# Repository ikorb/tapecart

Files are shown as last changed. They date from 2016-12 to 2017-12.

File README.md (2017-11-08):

# tapecart #

tapecart - a tape port storage pod for the C64

Copyright (C) 2013-2017 by Ingo Korb <ingo@akana.de>  
All rights reserved.  
Idea by enthusi  

# About #

The tapecart is a low-cost flash storage device for the Commodore 64's
tape port. This repository contains source code and documentation
related to it and will one day contain the schematics and layout files too.

# Structure of the repository #

This repository is organized as follows:

* doc

    This directory contains general documentation regarding the
    tapecart like the protocol it uses to communicate with the C64.

* src-c64

    This directory containts the source code for the C64-side
    software, currently the initial loader and the flashtool.

* src-firmware

    This directory contains the source code for the firmware running
    on the tapecart.

* hardware

    This directory contains schematics and layout for various hardware
    variants of the tapecart.

* mass-programmer

    This directory contains schematics, layout and software for a
    Raspberry Pi addon board that can be used for mass-programming
    tapecarts.

Schematics and layout for the tapecart itself will be released at a
later date.

# License #

The firmware itself is distributed under the following conditions:

    Redistribution and use in source and binary forms, with or without
    modification, are permitted provided that the following conditions
    are met:
    1. Redistributions of source code must retain the above copyright
       notice, this list of conditions and the following disclaimer.
    2. Redistributions in binary form must reproduce the above copyright
       notice, this list of conditions and the following disclaimer in the
       documentation and/or other materials provided with the distribution.

    THIS SOFTWARE IS PROVIDED BY THE REGENTS AND CONTRIBUTORS ``AS IS'' AND
    ANY EXPRESS OR IMPLIED WARRANTIES, INCLUDING, BUT NOT LIMITED TO, THE
    IMPLIED WARRANTIES OF MERCHANTABILITY AND FITNESS FOR A PARTICULAR PURPOSE
    ARE DISCLAIMED.  IN NO EVENT SHALL THE REGENTS OR CONTRIBUTORS BE LIABLE
    FOR ANY DIRECT, INDIRECT, INCIDENTAL, SPECIAL, EXEMPLARY, OR CONSEQUENTIAL
    DAMAGES (INCLUDING, BUT NOT LIMITED TO, PROCUREMENT OF SUBSTITUTE GOODS
    OR SERVICES; LOSS OF USE, DATA, OR PROFITS; OR BUSINESS INTERRUPTION)
    HOWEVER CAUSED AND ON ANY THEORY OF LIABILITY, WHETHER IN CONTRACT, STRICT
    LIABILITY, OR TORT (INCLUDING NEGLIGENCE OR OTHERWISE) ARISING IN ANY WAY
    OUT OF THE USE OF THIS SOFTWARE, EVEN IF ADVISED OF THE POSSIBILITY OF
    SUCH DAMAGE.

Please note that the firmware source code includes third-party header files
taken from the Atmel Software Framework. Please check its
[README](src-firmware/README.md) for more details.

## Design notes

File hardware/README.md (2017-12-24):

# tapecart hardware #

This directory contains KiCAD schematics and layout for three
different implementations of the tapecart:

* DIY

    This version of the tapecart is optimized for DIY builders - it
    does not require any SMD components. Since DIP versions of the
    flash chips are a bit hard to source, it has an alternate
    footprint for using an SMD flash chip instead. The firmware for
    this version must be compiled using the config file "config-diy".
    A precompiled hex file is located in the subdirectory "firmware".

* SMD-Onesided-R1 and SMD-Twosided-R1

    These two versions of the tapecart are optimized for cost, using
    SMD components. Both are electrically the same, but one of them
    saves a bit more board space by placing components on both sides
    of the board. The firmware for both of these versions must be
    compiled using the config file "config-release1". A precompiled
    binary is located in the subdirectory "firmware".

* duotape and duotape-riser

    A simple tapecart-compatible tapeport switch, e.g. to switch
    between two tapecarts or a tapecart and a Datasette(-emulator).
    duotape is the main switch PCB, duotape-riser contains a layout
    for a really trivial adapter board in case you don't have a 3.96mm
    stripboard available.

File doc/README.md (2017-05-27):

This directory contains docs about various parts of the tapecart project.

Currently available:
-    [Programmer's Reference](ProgRef.md)
-    [TCRT file format specification](TCRT%20Format.md)

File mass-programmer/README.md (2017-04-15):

# tapecart mass programmer #

The tapecart mass programmer can be used to flash the firmware of a
newly-built tapecart and write data to its flash memory without
requiring a C64. It is implemented as an addon board for a Raspberry
Pi. Although in theory it should work with almost any version of the
Raspberry Pi, it has only been tested with a Raspberry Pi 2.

The finished programmer (without cable) looks like this:

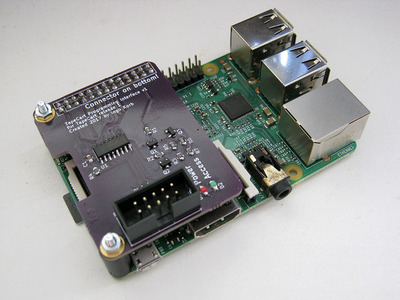
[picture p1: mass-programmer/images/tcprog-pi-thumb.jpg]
Picture of tapecart mass programmer


## Hardware ##

The schematics and layout for the mass programmer are in the
[kicad](kicad) subdirectory. It includes a PDF version of the
schematic for easier previewing as well as pre-generated gerber files
suitable for fabrication. A BOM file in CSV format is included as
well.

To connect the programmer board to the tapecart, a cable with a 10-pin
2x5 connector on one end and an 8-pin 1.27mm pin header (pin 7
removed) on the other end is required. Since the pins on the 10-pin
connector and the 8-pin header are connected 1:1, the easiest way to
construct this is to use an IDC plug for the 10-pin side as the ribbon
cable has the same pin pitch as the 8-pin header on the other end. If
you do this, pin 7 on the cable will be unused as this pin must be
removed from the 8-pin header to ensure that it cannot be inserted the
wrong way. It is recommended to select a 1.27mm pin header with long
pins as they will have more flexibility, making better contact to the
plated vias on the tapecart's circuit board.

The mass programmer has two LEDs, a red and a green one. The red LED
indicates that the tapecart connected to the mass programmer is
currently powered. The green LED mirrors the state of the tapecart's
own LED, the programing software uses it to show that data is being
written.

The mass programmer-to-tapecart connection is designed to allow
hot-plugging - in fact, a tapecart must not be connected to it while
the Raspberry Pi boots as the GPIO pins may not be in the correct state.

## Software ##

To use the mass programmer, a Linux installation with a number of
additional software packages is needed on the Raspberry Pi - see the
section below for some notes how to install and configure a new
Raspbian system to meet these requirements.

The scripts used for controlling the mass programmer are in the
[scripts](scripts) subdirectory.

The most important script is ``prepare.sh``, which sets up the basic
configuration of the Raspberry's GPIO lines. It must be run again
every time the Raspberry Pi is booted and no tapecart must be
connected to the mass programmer before this script has been run!

The scripts ``poweron.sh`` and ``poweroff.sh`` turn the poer to the
tapecart on or off. If the power is on, the red LED on the mass
programmer board lights up. You must only connect or disconnect a
tapecart to the mass programmer while the red LED is off.

The script ``reset-to-uart.sh`` switches the tapecart into its remote
command mode, which is used to program it using the mass
programmer. It must be run before tcprog.rb can communicate with the
tapecart, but it can only work if the tapecart's microcontroller has
been programmed with its firmware using OpenOCD.

The program ``tcprog.rb`` is the main programming tool. It uses the
remote command mode to program the flash contents of the tapecart,
similar to the flashtool on the C64. Please use ``tcprog.rb --help``
to see a short summary of its command line options.

An example full-device programming script is included as
``massprog.sh``. It needs three arguments, the firmware binary, the
initial loader binary and a single-file PRG file which are written to
a tapecart. This process makes a just-assembled, blank tapecart ready
for use with a C64, but it can also be used to rewrite the data on an
already-programmed tapecart. Feel free to customize it as needed, for
example to leave out the firmware and loader programming steps is you
just want to rewrite the contents of a pre-programmed cart.

The firmware of the tapecart's microcontroller is programmed using a
sufficiently recent version of [OpenOCD](http://openocd.org). A
suitable ``openocd.conf`` can also be found in the [scripts](scripts)
subdirectory.

## Setting up Raspbian ##

Quick notes on setting up a Raspbian environment suitable for the mass
programmer, assuming that you know your way around a Linux command line:

* use [NOOBS](https://www.raspberrypi.org/downloads/noobs/) (or NOOBS
    Lite) to install a fresh copy of Raspbian (last tested using NOOBS
    version 2.0, but it should also work with later versions)
* disable the serial console by editing ``/boot/cmdline.txt``, remove
    the statement ``console=serial0,115200`` and reboot afterwards
* install a few required packages using ``sudo apt-get install
    libusb-1.0-0-dev libusb-dev gawk ruby-dev``
* install the serial port library for Ruby using ``gem install
    --user-install serialport``
* install a sufficiently-recent version of OpenOCD, meaning at least
    version 0.10.0 - the package in Raspbian is probably too old!

You can verify parts of the installation by running ``./tcprog.rb
--help`` - if it just shows the command line options, Ruby and the
required serialport library are working correctly.

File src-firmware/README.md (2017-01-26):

# tapecart firmware sources #

tapecart - a tape port storage pod for the C64

Copyright (C) 2013-2017 by Ingo Korb <ingo@akana.de>  
All rights reserved.  
Idea by enthusi  

# About #

This directory contains the firmware sources for the Tapecart. They
can be built for various hardware, currently there are configurations
for early and late prototypes as well as the first release carts.

# Compiling #

To compile an AVR version of the firmware (used in prototypes), a
standard AVR gcc toolchain and avr-libc supporting at least the C11
standard is required.

To compile a SAMD09 version of the firmware (used in the first release
carts), an embedded ARM GCC toolchain is required. The [GNU ARM
Embedded
Toolchain](https://developer.arm.com/open-source/gnu-toolchain/gnu-rm)
should work fine.

The selection of the target configuration is made on the `make`
command line using the `CONFIG` variable, e.g. `make
CONFIG=configs/config-earlyproto` to compile a version of the firmware
suitable for early prototype boards.

# Using #

Please see the [doc](../doc) directory one level up.

# License #

The firmware itself is distributed under the following conditions:

    Redistribution and use in source and binary forms, with or without
    modification, are permitted provided that the following conditions
    are met:
    1. Redistributions of source code must retain the above copyright
       notice, this list of conditions and the following disclaimer.
    2. Redistributions in binary form must reproduce the above copyright
       notice, this list of conditions and the following disclaimer in the
       documentation and/or other materials provided with the distribution.

    THIS SOFTWARE IS PROVIDED BY THE REGENTS AND CONTRIBUTORS ``AS IS'' AND
    ANY EXPRESS OR IMPLIED WARRANTIES, INCLUDING, BUT NOT LIMITED TO, THE
    IMPLIED WARRANTIES OF MERCHANTABILITY AND FITNESS FOR A PARTICULAR PURPOSE
    ARE DISCLAIMED.  IN NO EVENT SHALL THE REGENTS OR CONTRIBUTORS BE LIABLE
    FOR ANY DIRECT, INDIRECT, INCIDENTAL, SPECIAL, EXEMPLARY, OR CONSEQUENTIAL
    DAMAGES (INCLUDING, BUT NOT LIMITED TO, PROCUREMENT OF SUBSTITUTE GOODS
    OR SERVICES; LOSS OF USE, DATA, OR PROFITS; OR BUSINESS INTERRUPTION)
    HOWEVER CAUSED AND ON ANY THEORY OF LIABILITY, WHETHER IN CONTRACT, STRICT
    LIABILITY, OR TORT (INCLUDING NEGLIGENCE OR OTHERWISE) ARISING IN ANY WAY
    OUT OF THE USE OF THIS SOFTWARE, EVEN IF ADVISED OF THE POSSIBILITY OF
    SUCH DAMAGE.

Please note that the source code includes third-party header files
taken from the Atmel Software Framework in the
[samd09/include](samd09/include) subdirectory, which come with their
own license conditions. Please check the files themselves for details.

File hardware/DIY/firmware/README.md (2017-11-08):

# tapecart-diy firmware #

The file "tapecart.hex" is a precompiled firmware binary for the DIY
hardware version of the tapecart and has been compiled for an
ATtiny44.

Recommeded fuse settings for the ATtiny44 are:

* lfuse: ef
* hfuse: d5
* efuse ff

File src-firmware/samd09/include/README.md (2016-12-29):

This directory contains the include files from the ARM CMSIS and
register definition header files from the Atmel Software Framework,
extracted from ASF version 3.28.1. Both are licensed under BSD-style
licenses, please check the headers of the files itself for details.

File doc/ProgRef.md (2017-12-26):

# Tapecart Programmer's Reference #

This document describes the Tapecart from a programmer's perspective -
i.e., how to communicate with it to read and write data.

## Intro ##

The tapecart is a small module connected to the C64's tape port which
allows a program running on the C64 to access its on-board flash
memory. It supports three different modes:

1. Streaming mode
2. Fastload mode
3. Command mode

Modes are described in detail below. The tapecart always starts in
streaming mode to allow the user to load an initial program using
Shift+Run/Stop. To ensure this load operation happens as fast as
possible, the tapecart only supports a two-byte-long program,
overwriting a vector to cause an auto-start in the tape buffer. This
auto-started code can be programmed independently of the main flash,
but a default version is supplied that uses fastload mode to load a
pre-defined block of flash into the C64's memory and starts it.

Switching from streaming mode to either fastload mode or command mode
is accomplished by sending a bit sequence using the write and motor
lines, which is detailed in the "Streaming mode" section below.

To ensure that the user can always run the initial program again, the
tapecart needs to detect if the C64 is reset and return to streaming
mode. It does this by monitoring the motor line: If at any point in
the Fastload or Command modes the motor line becomes active, it
immediately returns to streaming mode. To switch back to the previous
mode, the bit sequence needs to be sent again.

The fastload mode is intended to be mainly used by the default
loader. It sends a small header to the C64 followed by data read from
the flash memory. It uses a fast 2-bit protocol that can reach
transmission speeds of around 9500 bytes/second. If only a single
one-filed program is intended to be loaded from the tapecart, this
mode is all that is needed and the flashtool can set up everything as
needed while writing the program to flash. The default loader uses a
JMP to a programmable start address to start the program it has
loaded, but it is simple to add a small header that simulates a RUN
for programs started from BASIC. More defailts about the fastload mode
are given in the section titled "Fastload mode".

The third, and most flexible mode is command mode. In this mode, the
tapecart listens for commands that can be used to read, wrrite and
erase the flash memory as well as set parameters like the length of
the data block used for fastload mode. With the exception of the
READ\_FLASH\_FAST command, all data is transmitted and received using
1-bit protocols that are not timing critical - so they could for
example be used to load data while raster interrupts are still used
for effects. Of course a variation of the fast 2-bit protocol used by
the fastload mode is also available, but it cannot tolerate
interrupts, badlines or sprites.

Since the tapecart is based on flash memory, it can be read freely
from any starting byte, but writing is more limited. Data is organized
in pages of a fixed length and only full pages should be written -
writing a partial page results in undefined data in the remaining
bytes of the page. Furthermore, before a page can be written, it must
be erased which is only possible in blocks that are a multiple of the
page size and aligned to the same multiple. The exact values for these
parameters may vary between tapecarts depending on the availability of
cheap flash chips, so a command is available to read the details of
the tapecart that is currently connected. It is expected though that
all carts will stay within these parameters:

-   memory size 2 MByte (2,097,152 byte) or more, although a 64KByte
    version for onefilers might appear
-   page size 4096 bytes or less (currently 512 byte on early
    prototypes, 256 byte on initial release)
-   erase block size 64 KByte or less (64KB on early prototypes, 4KB
    on initial release)

To simplify working with tapecarts that have different erase block
sizes, a command is available that will always erase a 64 KByte block
(aligned at a 64 KByte boundary), no matter what the actual erase
block size is. If you use the tapecart as a read-only device, you do
not need to worry about page size or erase block sizes since the
flashtool will handle these details for you. However, if you plan to
write to the tapecart yourself from your application, you need to plan
your memory layout to ensure that no vital data is erased when you
erase a block before writing to it.

## Streaming mode ##

In streaming mode, the tapecart basically behaves like a datasette
with an endless tape. It sends a pulse stream to the C64 that contains
an auto-starting initial loader program in the tape buffer, which uses
$0302 as its auto-start vector. The default initial loader switches to
fastload mode to load the main program and tries to start it using
RUN. A custom initial loader can be installed using the flash tool (or
the WRITE_LOADER command), but it is limited to 171 bytes and will
always be started at $0351 using the $0302 vector.

After each transmission of the initial loader, the tapecart releases
the sense line of the tape port for about 200 milliseconds. This is
necessary to resume loading in case an initial load attempt was
cancelled using RUN/STOP. After this delay has passed, but before
restarting the pulse stream, the tapecart checks if it has received a
mode switch sequence. The tapecart is switched to fastload or command
mode by sending one of two bit sequences on the write line. Each time
the motor is turned on, the state of the write line is sampled and a
16-bit shift register is shifted left by one bit, using the current
value on the write line as its lowest bit. A rough approximation as C
code:
    
    shift_reg = shift_reg << 1;
    if (get_write())
      shift_reg = shift_reg | 1;

The tapecart checks the contents of the shift register occasionally,
the maximum time between two checks should be less than two
milliseconds. If the shift register contains the value $ca65, it
enters fastload mode; if the value is $fce2, it enters command
mode. The shift register is reset every time the transmission of the
initial loader's header block, so it may be a good idea to start
transmitting it only if the sense line is low.

Please note that turning off the motor is very slow on some C64 board
revisions, it can take about a millisecond (~1000 cycles) until the
signal has decayed sufficiently. On the other hand, turning on the
motor is very fast and no delay should be needed - do make sure that
the level on the write line has already been set before turning the
motor bit in $01 on, otherwise the mode switch sequence may not be
detected reliably. You should turn off the motor after the sequence
has been transmitted, otherwise the tapecart will immediately return
to streaming mode.

A sample implementation for the mode switch sequence with a value of
$ca65 can be found in the initial loader, a sample implementation for
entering command mode can be found in the C sources of the flash tool
(tapecartif.c).

## Fastload mode ##

Fastload mode transmits a selected part of the flash memory using a
fast 2-bit fixed-timing protocol which reaches ~9500 bytes/second. The
protocol is similar (but not identical) to the fast 2-bit read used in
command mode - you shouldn't need to worry about it unless you want to
make extensive modifications to the default initial loader.

Fastload mode can transmit up to 65535 bytes to the C64 which should
be sufficient for most purposes. The length and offset of the data
block in flash memory as well as the start address that the initial
loader should jump to after loading can be set using the
WRITE_LOADINFO command. The default initial loader can load data
anywhere in the C64's RAM, even in the RAM below I/O at $d000. It
treats the first six bytes it receives as an "info block" which
specifies the start and end addresses of the data in the C64 as well
as the address to jump to after loading. You do not need to worry
about this info block though, the tapecart automatically calculates it
for you.

In the flash memory, the program to be loaded is structured exactly
the same as a PRG file: Two bytes that specify the load address,
followed by data. Since there is no way to detect the length of a PRG
file, the number of bytes (including the two bytes for the load
address) must be set using the WRITE_LOADINFO command. Please be aware
that it may be a bad idea to load over the tape buffer because the
initial loader runs from there, or over zeropage addresses $aa to $af
where the default initial loader stores a few bytes of data.

The default initial loader uses a JMP to start the program it has
loaded. At this point, the autostart vector has been reset to its
default value, the screen is turned back on and interrupts are enabled
again. If you need to start a BASIC program with RUN instead, you can
add a short header just before $0801 that does a few calls into the
BASIC ROM to simulate RUN - the flashtool contains an implementation
of this for its onefiler-writing mode. The contents of the CPU
registers are unspecified and may change without notice, except as
described in the section *Data Block Offset option* below.

## Command mode ##

In command mode, the tapecart expects to receive commands using a
1-bit C64-timed protocol (similar to an IRQ loader for the 1541) and
sends its answer with a 1-bit C64-timed protocol unless the command
specifies something different.

When the tapecart has detected the command mode magic value at the end
of the 200ms pause, it sets the sense line high and waits until the
write line is high. Even though the motor line is off at this time, it
will resume sending pulses until the write line is low again, after
which it waits to receive a command. If at any time during this
process the motor line turns on again, the tapecart aborts and enters
streaming mode again. In tabular form, the process looks like this:

1.  send the magic number for command mode ($fce2) - the motor should
    be off after sending it
2.  delay for one millisecond (~1000 cycles) to ensure that the motor
    signal is really off (unless the delay is already at the end of
    your send loop in step 1)
3.  set the write line high
4.  wait until the sense line is high
5.  wait until at least three pulses on the read line have been
    received (CIA 1 ICR $dc0d, bit 4)
6.  set write low

To send a command to the tapecart in this mode, send a single byte
with the command code to the tapecart using the byte transmit scheme
described below, followed by any parameter bytes that may be needed
(zero for some commands). If the command returns data, read it using
the byte receive scheme described below or the fast 2-bit read for the
READ_EXTMEM_FAST command. Currently, sample implementations of the
transmit and receive schemes only exist in C form in the sources of
the flashtool (tapecartif.c).

While not sending a command, the write line should be low and the
sense line should be configured as input. The tapecart sets sense low
while it is busy and high to signal that it is ready to receive a byte
- this was chosen so that the kernal IRQ handler can be told to not
turn on the motor (which would exit command mode) by writing a
non-zero value in $c0.

Command mode stays active after a command is processed. It will be
exited only if an unknown command byte is received, the EXIT command
is received or the motor line becomes active (used to detect a C64
reset). With the current code base, the device's LED is on while it is
in command mode and turns off as soon as it is exited, but there are
also two commands to explicitly turn the LED on or off.

### Byte transmit (C64->Tapecart) ###

If you use the kernal interrupt handler, it is recommended to disable
interrupts while sending bytes to the tapecart because the kernal's
interrupt handler would turn on the motor, kicking the tapecart out of
command mode. It can also be useful to set $c0 to a non-zero value
after transmitting a byte but before re-enabling interrupts because
the tapecart may signal a busy state with the sense line low for some
time. A non-zero value in $c0 ensures that the kernal's interrupt
handler will not turn on the tape motor in this case.

The byte transmission is a C64-clocked protocol, using the write line
as a clock signal and the sense line to transmit data. Please note
that in this case the direction of the sense line is opposite to the
normal usage in the C64, so bit 4 of $00 must be set to 1 temporarily
while a byte is sent. In tabular form, the protocol looks like this:

1.  If you use the kernal interrupt handler, turn off interrupts
2.  wait until sense is high (tapecart is ready to receive)
3.  switch the sense line to output (set bit 4 of $00)
4.  for all 8 bits of the byte, repeat the following, starting with
    the most-significant bit:
    1.  set the sense line to the value of the bit
    2.  set the write line high
    3.  set the write line low
5.  set the sense line high
6.  set the sense line low
7.  set the sense line to input again (clear bit 4 of $00)
8.  If you use the kernal interrupt handler, set $c0 to a non-zero
    value and re-enable interrupts

Please note that steps 5-7 are needed so the tapecart can set its own
sense pin to output without risking that the C64's sense pin is also
still set to be an output. The tapecart will switch its sense pin to
output 10 microseconds (~10 cycles) after it sees the high->low
transition and since the state of the C64's pin is known at this
point, this is safe even if step 7 on the C64 is delayed, e.g. due to
a badline.

After receiving a byte, the tapecart will set the sense line low until
it has finished processing the received byte.

### Byte receive (Tapecart->C64) ###

If you use the kernal interrupt handler, it is recommended to disable
interrupts while receiving bytes from the tapecart because the
kernal's interrupt handler would turn on the motor, kicking the
tapecart out of command mode. It can also be useful to set $c0 to a
non-zero value after receiving a byte but before re-enabling
interrupts because the tapecart may signal a busy state with the sense
line low for some time. A non-zero value in $c0 ensures that the
kernal's interrupt handler will not turn on the tape motor in this
case.

The byte reception is a C64-clocked protocol, using the write line as
a clock signal and the sense line to transmit data. Unlike the
transmit protocol, all lines are used in their standard direction, so
no accesses to $00 are needed. In tabular form, the protocol looks
like this:

1.  If you use the kernal interrupt handler, turn off interrupts
2.  wait until sense is high (tapecart is ready to receive)
3.  set the write line high
4.  repeat 8 times for the bits of a byte, the most-significant bit is
    received first:
    1.  set the write line low
    2.  set the write line high
    3.  if the sense line is high, a 1 bit has been received; if it is
        low, a 0 bit has been received
5.  set the write line low
6.  If you use the kernal interrupt handler, set $c0 to a non-zero
    value and re-enable interrupts

After sending a byte, the tapecart will set the sense line low until
it is ready to transmit (or receive) another byte.

### Commands ###

A number of commands are defined for the tapecart. Some of them are
mostly useful for the flashing tool, but have been documented here
anyway for completeness. If the tapecart receives a command byte that
it does not know, it switches to streaming mode.

Some commands expect to receive additional bytes with command
arguments. Some commands send a reply, some do not. Numerical values
that exceed 8 bit are sent in little endian (low byte first). Both
parameters and replies are given in the order they are expected/sent.

#### Command $00: EXIT ####
This command exits to streaming mode.

No parameters, no reply.

#### Command $01: READ_DEVICEINFO ####
This commands reads a string containing a device identification.

No parameters.

**Reply:**

PETSCII string, 0-terminated

#### Command $02: READ_DEVICESIZES ####
This command reads the total size of the tapecart's memory, its page
size and its erase block size.

No parameters.

**Reply:**

1.  3 byte total size (in byte)
2.  2 byte page size (in byte)
3.  2 byte erase block size (in pages!)

If the erase block size is 0, direct byte write is supported and no
erase commands are needed.

#### Command $03: READ_CAPABILITIES ####
This command reads a bit field that specifies which extended
capabilities are available on this tapecart. If an additional
capability is available, its bit is set to 1. Currently, no extended
capabilities are defined, so the value returned by this command
consists of 4 $00 bytes.

No parameters.

**Reply:**

1. 4 byte flags

#### Command $10: READ_FLASH ####
This commands reads from the tapecart's flash memory.

**Parameters:**

1.  3 byte start address
2.  2 byte length (in bytes)

**Reply:**

1.  n byte data

Attempting to read using a length of 0 bytes results in undefined behaviour.
Reading from an address beyond the flash's size (either by specifying
an invalid start address or a length that results in an access beyond
the flash size) results in undefined behaviour.

#### Command $11: READ\_FLASH\_FAST ####
This command reads from the tapecart's flash memory and sends the data
with a fast 2-bit protocol.

**Parameters:**

1.  3 byte start address
2.  2 byte length (in bytes)

**Reply:**

This command does not use the usual 1-bit protocol to reply!

1.  n byte data

Attempting to read using a length of 0 bytes results in undefined behaviour.
Reading from an address beyond the flash's size (either by specifying
an invalid start address or a length that results in an access beyond
the flash size) results in undefined behaviour.

Since the alternative protocol used by this command is timing
sensitive, below is a sample code snippet that implements a compatible
byte reception subroutine. If you modify it, please ensure that all
read/write accesses and direction changes on the write/sense lines
happen at the same clock cycle as the original, relative to the point
where the write line is set high. The timing was chosen to be safe on
both PAL and NTSC machines, even if the internal clock of the
tapecart's controller has worst-case deviation.

The code assumes that the CPU will not be interrupted by any VIC
memory access. The easiest way to ensure this is to blank the screen
and wait for 20ms, but any method that ensures that the cycle-counted
part of the code is not delayed should work.

```
;;   getbyte_fast.s: Fast byte read
;; 
;;   Note: This uses the opposite level on sense to determine ready-ness
;;         compared to the loader mode!
;;

        .export _tapecart_getbyte_fast
_tapecart_getbyte_fast: 
        ;; wait until tapecart is ready (sense high)
        lda #$10
rdyloop:        
        bit $01
        beq rdyloop

        ;; (this would be a nice place to check if a badline is coming up)

        ;; send our own ready signal
        ldx #$38
        lda #$27
        stx $01                 ; set write high (start signal)
        sta $00                 ; 3 - switch write to input
        nop                     ; 2 - delay

        ;; receive byte
        lda $01                 ; 3 - read bits 5+4
        and #$18                ; 2 - mask
        lsr                     ; 2 - shift down
        lsr                     ; 2
        eor $01                 ; 3 - read bits 7+6
        lsr                     ; 2
        and #$0f                ; 2 - mask
        tax                     ; 2 - remember value

        lda $01                 ; 3 - read bits 1+0
        and #$18                ; 2 - mask
        lsr                     ; 2 - shift down
        lsr                     ; 2
        eor $01                 ; 3 - read bits 3+2
        lsr                     ; 2
        and #$0f                ; 2 - mask
        ora nibbletab,x         ; 4 - add upper nibble

        ldx #$2f                ; 2 - switch write to output
        stx $00                 ; 3
        ldx #$36                ; set write low again
        stx $01

        rts

nibbletab:
        .byt $00, $10, $20, $30, $40, $50, $60, $70
        .byt $80, $90, $a0, $b0, $c0, $d0, $e0, $f0
```

Please note that the protocol used by this command is similar, but not
identical to the one used in fastload mode.

#### Command $12: WRITE_FLASH ####
This command writes to the tapecart's flash memory.

**Parameters:**

1.  3 byte start address
2.  2 byte length (in bytes)
3.  n byte data

No reply

Attempting to write using a length of 0 bytes results in undefined behaviour.
Writing to an address beyond the flash's size (either by specifying
an invalid start address or a length that results in an access beyond
the flash size) results in undefined behaviour.

The tapecart's firmware will ensure that page-crossings are handled
correctly if you want to write more than one page, but it does not
auto-erase the memory that is written to. If the data does not end at
the end of a page, the new content of the remaining bytes of the page
is undefined.

#### Command $13: WRITE\_FLASH\_FAST ####
This command is currently not implemented.

#### Command $14: ERASE\_FLASH\_64K ####
This command erases a 64KB block in the flash memory.

**Parameters:**

1.  3 byte address

The address can specify any byte within the intended 64KB block.

#### Command $15: ERASE\_FLASH\_BLOCK ####
This command erases a single erase block in the flash memory.

**Parameters:**

1.  3 byte address

The address can specify any bytes within the intended erase block. The
size of the erase block can be determined by using the
READ_DEVICESIZES command.

#### Command $16: CRC32_FLASH ####
This command calculates the CRC32 of an area of the flash memory contents.

**Parameters:**

1.  3 byte start address
2.  3 byte length (in bytes)

**Reply:**

1.  4 bytes CRC32

This command uses the standard CRC32 algorithm (polynomial
0x04c11db7), the same as e.g. Ethernet, ZIP or PNG.

#### Command $20: READ_LOADER ####
This command reads the current initial loader.

No parameters

**Reply:**

1.  171 byte loader

#### Command $21: READ_LOADINFO ####
This command reads the current initial loader auxillary data.

No parameters

**Reply:**

1.  2 byte data address
2.  2 byte data length
3.  2 byte call address
4.  16 byte file name

The data address and length in the reply refer to the tapecart's
external memory - the fastload mode starts to read at this address and
transmits as many bytes as specified here. After loading, it jumps to
the call address returned by this command. The file name is the name
shown by the C64 in the "FOUND ..." message when the user loads the
initial loader.

#### Command $22: WRITE_LOADER ####
This command writes a new initial loader to the tapecart.

**Parameters:**

1.  171 byte loader

No reply

#### Command $23: WRITE_LOADINFO ####
This command updates the initial loader auxilary data.

**Parameters:**

1.  2 byte data address
2.  2 byte data length
3.  2 byte call address
4.  16 byte file name

No reply

The data address and length refer to the tapecart's external memory -
the fastload mode starts to read at this address and transmits as many
bytes as specified here. After loading, the default initial loader
jumps to the call address set by this command. The file name is the
name shown by the C64 in the "FOUND ..." message when the user loads
the initial loader.

#### Command $30: LED_OFF ####
This command turns the LED on the tapecart off (if available). Please
note that the LED is turned on when command mode is entered.

No parameters, no reply.

#### Command $31: LED_ON ####
This command turns the LED on the tapecart on (if available). Please
note that the LED is already turned on when command mode is entered.

No parameters, no reply.

#### Command $32: READ_DEBUGFLAGS ####
This command reads the current debug flags.
See WRITE_DEBUGFLAGS below for details about the flags.

No parameters

**Reply:**

1.  2 byte debug flags

#### Command $33: WRITE_DEBUGFLAGS ####
This command sets the debug flags. These flags are intended to enable
features that may be useful when writing or debugging programs that
access the tapecart. The flags are non-persistent, a power cycle will
set all of them to 0 again. To enable a debug flag, set its bit in the
parameter of this command to 1; to disable it, set it to 0. To avoid
any chicken-and-egg problems when sending this command, the flash tool
has an option to set the debug flags.

**Parameters:**

1.   2 byte debug flags

No reply

Currently, there are two defined debug flags:

1.  SEND_CMDOK ($0001) - sends the characters 'O' and 'K' before a
    command byte is read. Probably not that useful when accessing a
    tapecart via the tape port, but helpful in the undocumented UART
    mode. You cannot set this flag with the menu option in the flash
    tool.
2.  BLINK_MAGIC ($0002) - show the current content of the magic value
    shift register by blinking the LED after each kernal loader
    cycle. The value is shown MSB-first, a long pulse of the LED
    stands for a 1-bit and a short pulse for a 0-bit. Please note that
    not all tapecarts are equipped with a LED and even on those they
    are the LED may not work.
3.  BLINK\_COMMAND ($0004) - similar to BLINK\_MAGIC, but shows the
    received command byte by blinking

#### Command $40: DIR_SETPARAMS ####
This commands sets the parameters for the directory lookup command
(see below). To simplify porting file-based programs to the tapecart,
the cart can look up a given "file name" in a directory stored in the
flash memory and return fixed-length data (e.g. a flash address and
length) associated with that file name.

**Parameters:**

1.  3 bytes flash address of the start of the directory
2.  2 bytes number of entries in the directory
3.  1 byte length of a file name in the directory (values over 16 will
    be limited to 16), called "n" below
4.  1 byte length of the data associated with a file name, called "m" below

No reply

Please see below for a description of the directory format.

#### Command $41: DIR_LOOKUP ####
This command looks up a file name in the directory that was set using
DIR_SETPARAMS and returns the associated data bytes if the name was
found.

**Parameters:**

1.  n bytes file name (n set by the third parameter of DIR_SETPARAMS)
    
**Reply:**

1.  1 byte "found" marker: 0 if the name was found, nonzero if not
2.  (only if byte 1 was 0)  m byte data (m set by the fourth parameter
    of DIR_SETPARAMS) 

A directory consists of a number of entries, each of which is a
fixed-length record with a length of n+m bytes. Each record contains a
file name (n bytes) followed by the data associated (m bytes) with
that file name. You get to decide yourself how that data is
structured, for example you could use the flash-address and length of
the actual file contents. The length of the data part of each entry in
the directory must be the same! File name comparison uses binary
matching with no wildcards, every single byte of the name to be looked
up must match the name in the flash exactly.

Commands from $f0 on are reserved for system functionality like
firmware updates and will not be documented here.

## Data Block Offset option ##

In order to allow multiple tapecart-utilizing programs to coexist on the
same tapecart, programs may support data block offsets. Such a program
is able to run even if its data is not stored starting from flash
address 0 by adding an offset to all addresses it sends to the
tapecart.

The selection of the program to start would be made by
another application which is started by the tapecart's initial loader,
for example a menu system allowing the user to choose from a list of
programs available on the tapecart. Implementation details for such a
menu system are beyond the scope of this reference, except for the
method used to pass the correct data block offset to the program to be
started.

A program that wants to declare support for data block offsets must be
supplied in TCRT format and it must set bit 1 of the misc. flags field
(see the [TCRT format specification](TCRT Format.md) for
details). Since a user may write such a program directly to a
tapecart without the use of an additional menu program, it must be
able to run even if no data block offset has been passed to it. This
can easily be implemented by using a default data block offset of 0
and replacing that with the actual offset if present.

Data block offsets are always integer multiples of the erase block
size, i.e. a multiple of 4096 byte for non-prototype tapecarts. In the
unlikely event that a future tapecart supports erase block sizes that
are not divisible by 256, the data block offset will be chosen so that
it is a multiple of 256.

### Checking for a data block offset ###

To indicate that a data block offset should be used, the loader
(e.g. the initial loader or a menu application) sets the Y register to
$4f (lower-case "o" in PETSCII). The data block offset itself is
stored in the zero-page at addresses $00fb and $00fc. If the Y
register contains any other value, no data block offset has been
passed and it should be assumed that the offset is 0.

An application that does not support data block offsets or that does
not need to read or write data from the tapecart at all may ignore any
data block offset passed to it.

Address $00fb in the zero-page holds the middle 8 bits of the data
block offset and address $00fc holds the top 8 bits of the data block
offset. The lowest 8 bits are not explicitly given anywhere, but can
be assumed to be 0, because the offset will always be a multiple of
256 or more.

### Precautions when working with data block offsets ###

You must make sure that you add the data block offset to all flash
addresses passed to the tapecart, both for read and write
accesses. How you do this is up to you - for example you could use
self-modifying code to change all addresses in your code or you could
add it before every access.

Do make sure that you correctly handle the offset for write accesses -
reading from an incorrect address will just give wrong data to
your program, but writing to an incorrect address will corrupt other
programs on the tapecart.

For additional safety, you may want to use the CRC32_FLASH command to
verify that the flash content starting at the current data block
offset is actually the data you expect to be there. This could also be
used to detect corruption caused by other programs writing to the
wrong flash address. If you do verify your data this way, remember to
exclude all flash pages that your program writes into.

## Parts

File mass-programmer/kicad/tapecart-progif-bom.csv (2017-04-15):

Reference | Value | Footprint | Notes
C1 | 100n | Capacitors_SMD:C_0805
D1 | LED RED | LEDs:LED_0805
D2 | LED GREEN | LEDs:LED_0805
P1 | CONN_02X13 | Pin_Headers:Pin_Header_Straight_2x13
P2 | CONN_02X05 | Connect:IDC_Header_Straight_10pins
Q1 | BSS138 | TO_SOT_Packages_SMD:SOT-23
Q2 | IRLML2244 | TO_SOT_Packages_SMD:SOT-23
Q3 | BSS138 | TO_SOT_Packages_SMD:SOT-23
R1 | 100 | Resistors_SMD:R_0805
R2 | 4k7 | Resistors_SMD:R_0805
R3 | 330 | Resistors_SMD:R_0805
R4 | 4k7 | Resistors_SMD:R_0805
R5 | 100 | Resistors_SMD:R_0805
R6 | 1M | Resistors_SMD:R_0805
R7 | 330 | Resistors_SMD:R_0805
U1 | 74HC4053 | Housings_SOIC:SOIC-16_3.9x9.9mm_Pitch1.27mm
U2 | D5V0F4U6SO | TO_SOT_Packages_SMD:SOT-23-6 | or D5V0P4UR6SO or similar (original type was 5V because of availability)

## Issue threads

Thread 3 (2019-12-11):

TCRT file size limit

dikdom, 2019-12-11:
Hello,
I read in the TCRT file format doc that `[..] to 2097152 (0x200000) for the full flash memory. A TCRT file with a larger value in this field is invalid. [...]` .
Is there any particular reason for that?
I mean there are cheap W25Q chips (W25Q32/64/128) having 4/8/16MB capacity which easily fit into the DIY board. Their size can also be autodetected so the firmware doesn't really have to be aware of the size during compile time.
Is it only because the SMD variant can't have more than 2MB and you want to keep it compatible? Or?
I'm working on elevating this limit by modifying the firmware. If you're interested in the autodetect code it's already in my forked repo.

Thanks!

ikorb, 2019-12-11:
The reason is compatibility: A conformant TCRT file will work with any existing TapeCart in the world, similar to EasyFlash cartridge images. Increasing this limit basically says "too bad, sucker" to anyone who bought a lower-capacity device, so I do not consider it acceptable to raise this limit.

Note that this does not preclude future devices that offers selectable TapeCart "banks" of 2MB each, similar to the EasyFlash 3.

dikdom, 2019-12-11:
It's your project. But I would see this as  a natural evolution of the tapecart. Those, who have 2MB tapecart will have a v1.0 fw and v1.0 TCRT file support. Fw v2.0 and Tcrt v2.0 has an improved feature set (larger address space), that wouldn't mean that you failed your followers/customers.
Please don't get me wrong, this is a cool project as is right now, but I can think this would improve it.

Anyway, for myself I will enhance it this way, but I use a simple eeprom burner to write the content to the flash chip. To write 8MB (or 16MB) content to the flash would take a day from the C64.

Closed 2019-12-11.

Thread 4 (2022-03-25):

Distribution of binaries without complying to license

mlorenzati, 2022-03-25:
Your HW and FW implementation is being used without complying to the licensing schema.
https://www.commodore64.com.ar/MLA-1113106513-tapecart-para-commodore-64128-pendrive-para-tu-commodore-_JM

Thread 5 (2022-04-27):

PCBWay gerbers

electron99, 2022-04-27:
Hello,

Is this PCBWay account yours?

https://www.pcbway.com/project/shareproject/Tapecart_for_C64_1560bea9.html

ikorb, 2022-04-27:
No

Closed 2022-04-27.

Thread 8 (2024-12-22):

Add an lgt8f328p hex compiled file

IoT64, 2024-12-22:
Can you add an lgt8f328p hex compiled file? It will be useful.

ikorb, 2024-12-22:
WTF is an lgt8f328p?

IoT64, 2024-12-22:
> WTF is an lgt8f328p?

A clone of ATMEGA328P.

https://github.com/dbuezas/lgt8fx

ikorb, 2024-12-22:
That chip is not pinout-compatible with the hardware in this repository, so just a .hex file would not be sufficient. The chip does not seem to be available from any reputable distributor either and there is no official english-language datasheet for it, so I don't see why I should put in the effort and money to redesign the hardware and port the software over.

If you want it, you'll have to do it yourself.

IoT64, 2024-12-22:
> That chip is not pinout-compatible with the hardware in this repository, so just a .hex file would not be sufficient. The chip does not seem to be available from any reputable distributor either and there is no official english-language datasheet for it, so I don't see why I should put in the effort and money to redesign the hardware and port the software over.
>
> If you want it, you'll have to do it yourself.

It is pin compatible (mini pro is), you don't need to redesign pcb only recompile with the correct hardware. Sorry but i ask it because i am not expert with GCC. If you wan't no problem, you aren't obligade. Thank you.

ikorb, 2024-12-22:
None of the links you provided shows a 14-pin DIL package at all and just from the part number it is clear that the chip is not even intended to be 1:1-replacement compatible with an ATtiny44. Furthermore, some of the links mention that the instruction timing is different, so the cycle-counted assembly code would require modifications to send data with the correct timing. This is absolutely not a "just recompile and it works" thing.

IoT64, 2024-12-22:
Sorry. Wrong github page. Please excuse me. I'm referring to another tapecart project, that uses your project.
[](https://github.com/KimJorgensen/tapecart)
Sorry again for my mistake!

Closed 2024-12-22.

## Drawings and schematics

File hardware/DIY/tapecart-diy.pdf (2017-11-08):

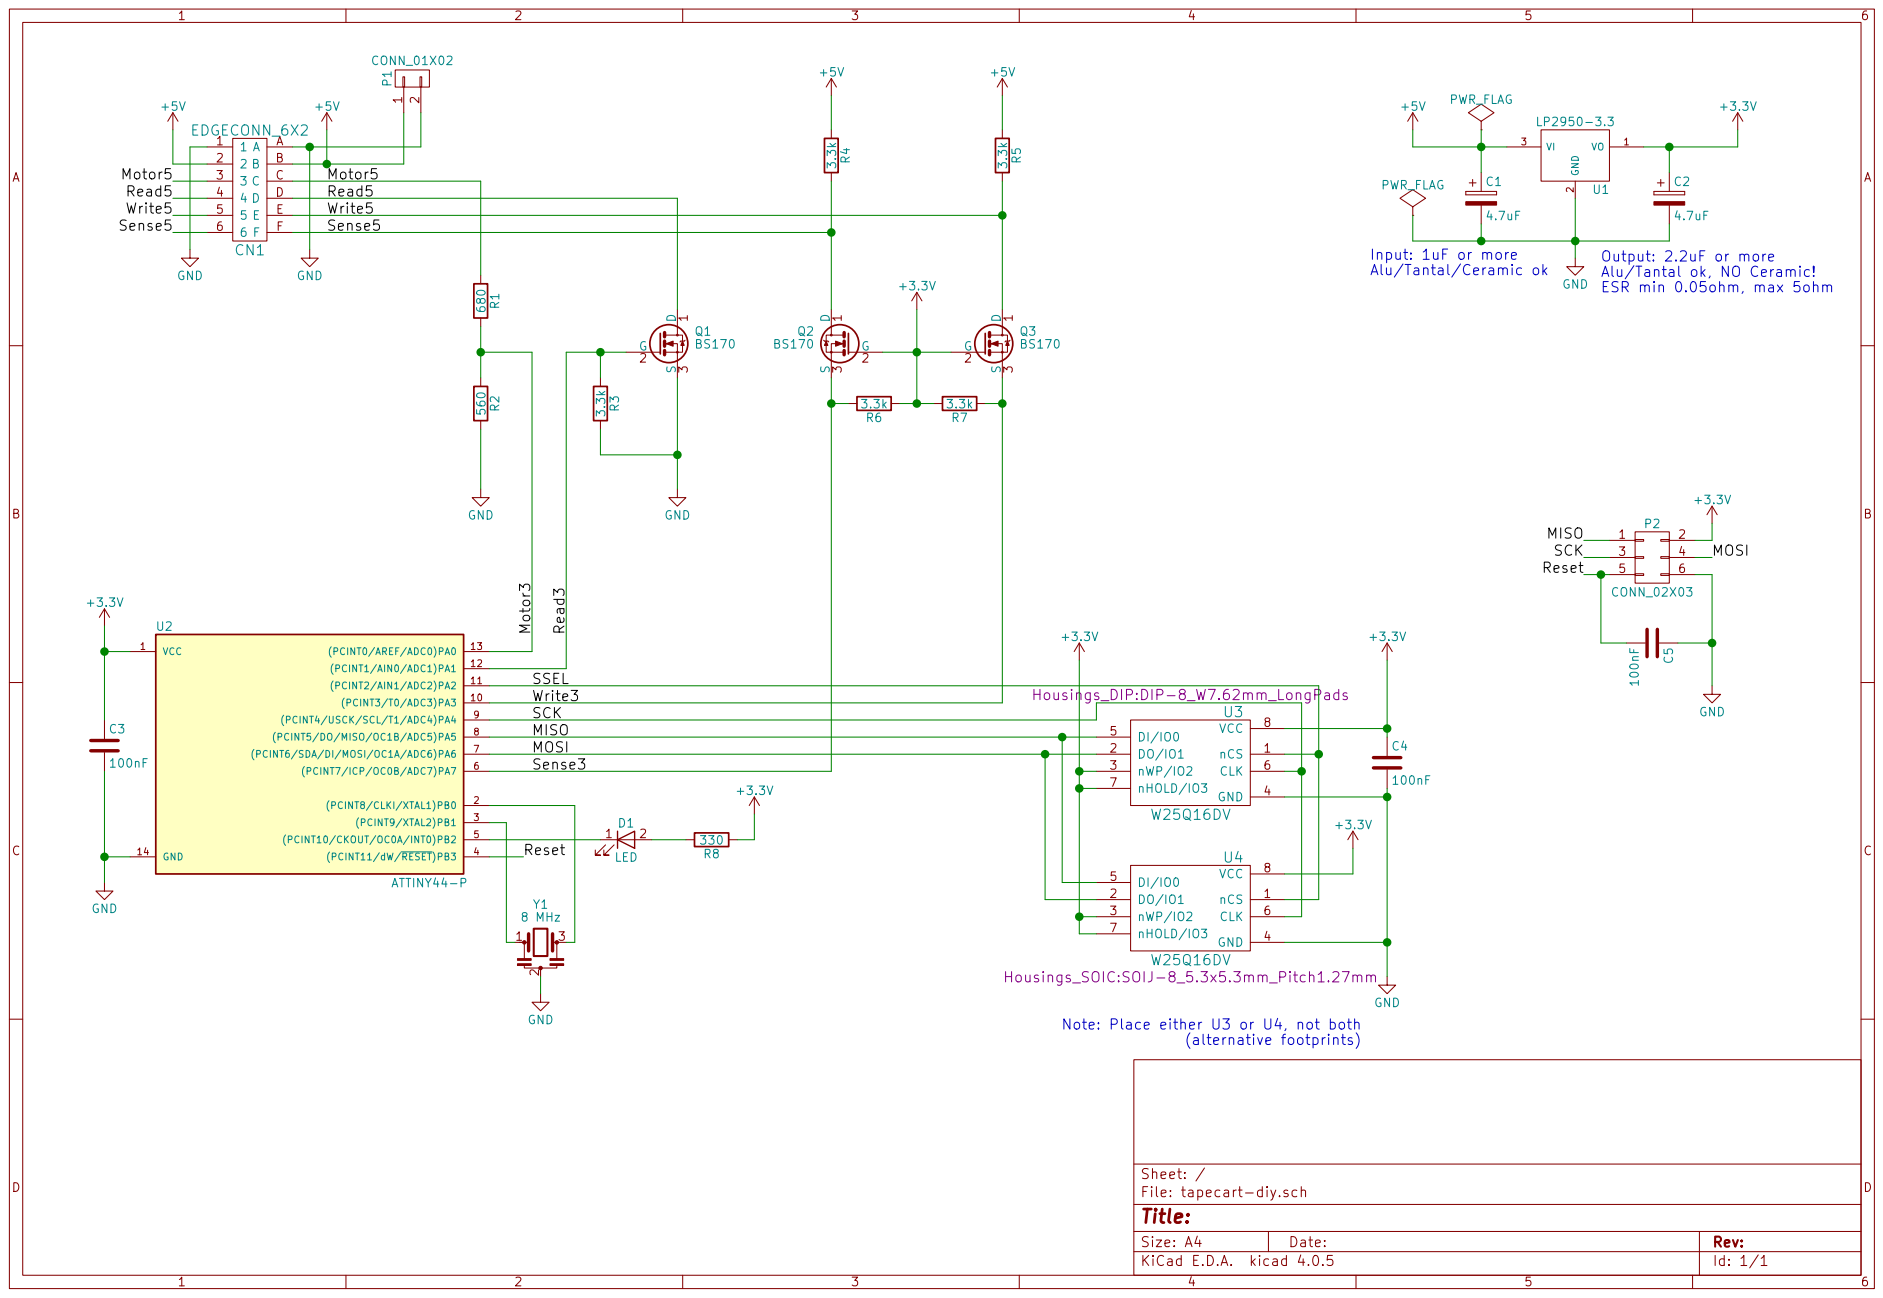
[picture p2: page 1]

Input: 1uF or more
Alu/Tantal/Ceramic ok

Output: 2.2uF or more
Alu/Tantal ok, NO Ceramic!
ESR min 0.05ohm, max 5ohm

Note: Place either U3 or U4, not both

File: tapecart-diy.sch Sheet: /
Id: 1/1 Title:

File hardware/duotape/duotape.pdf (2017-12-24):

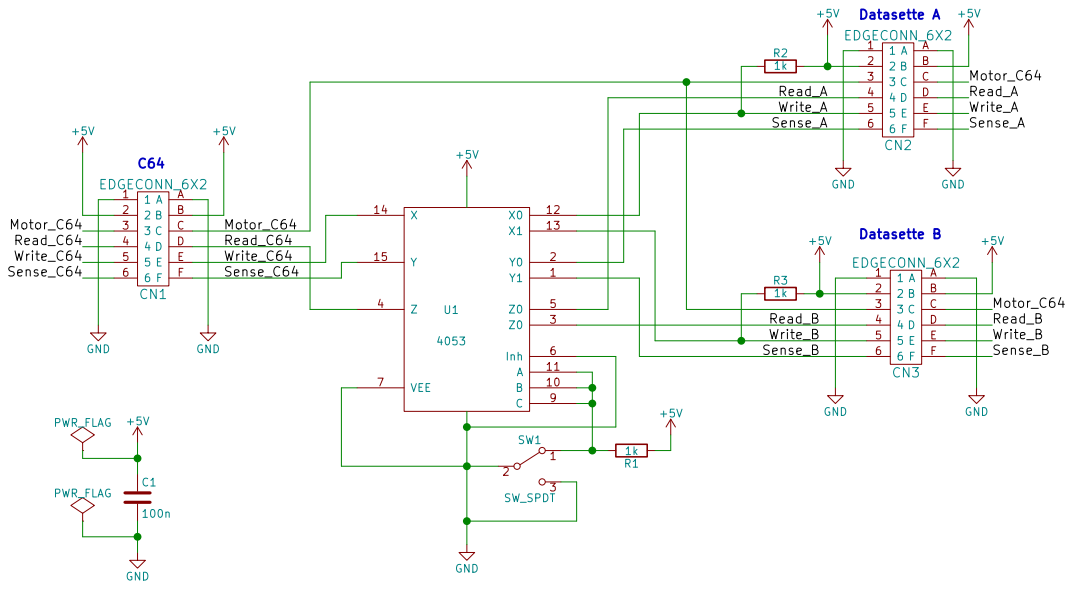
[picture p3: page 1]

Read_A | | 4 | | D
Write_A | 5 | | E
Sense_A

Read_B | 4 | | D
Write_B | 5 | E

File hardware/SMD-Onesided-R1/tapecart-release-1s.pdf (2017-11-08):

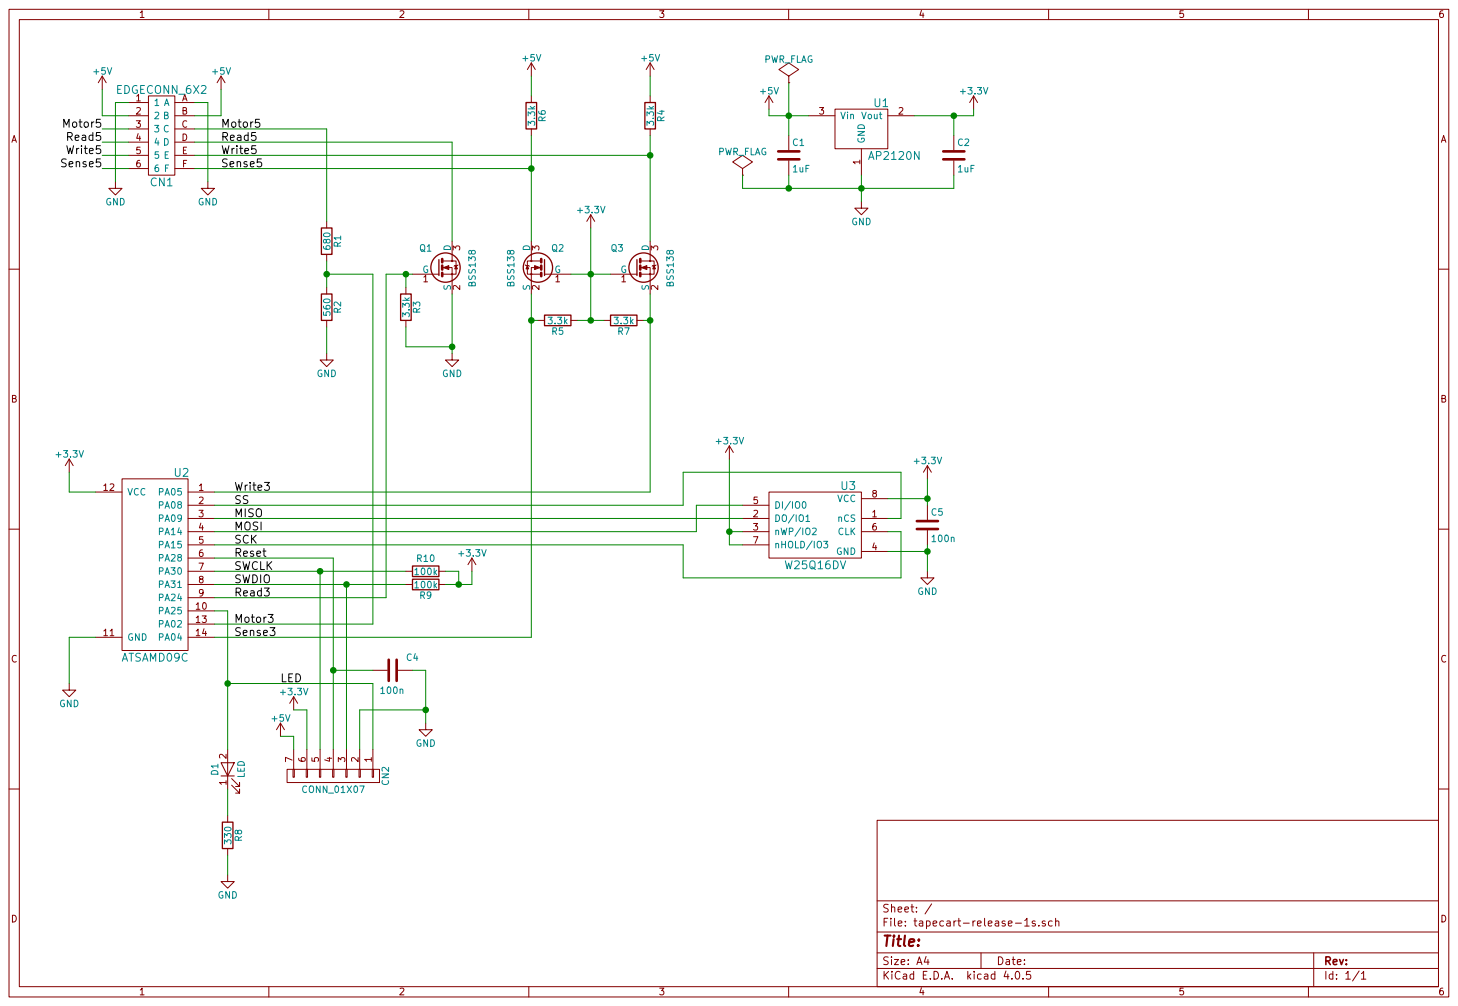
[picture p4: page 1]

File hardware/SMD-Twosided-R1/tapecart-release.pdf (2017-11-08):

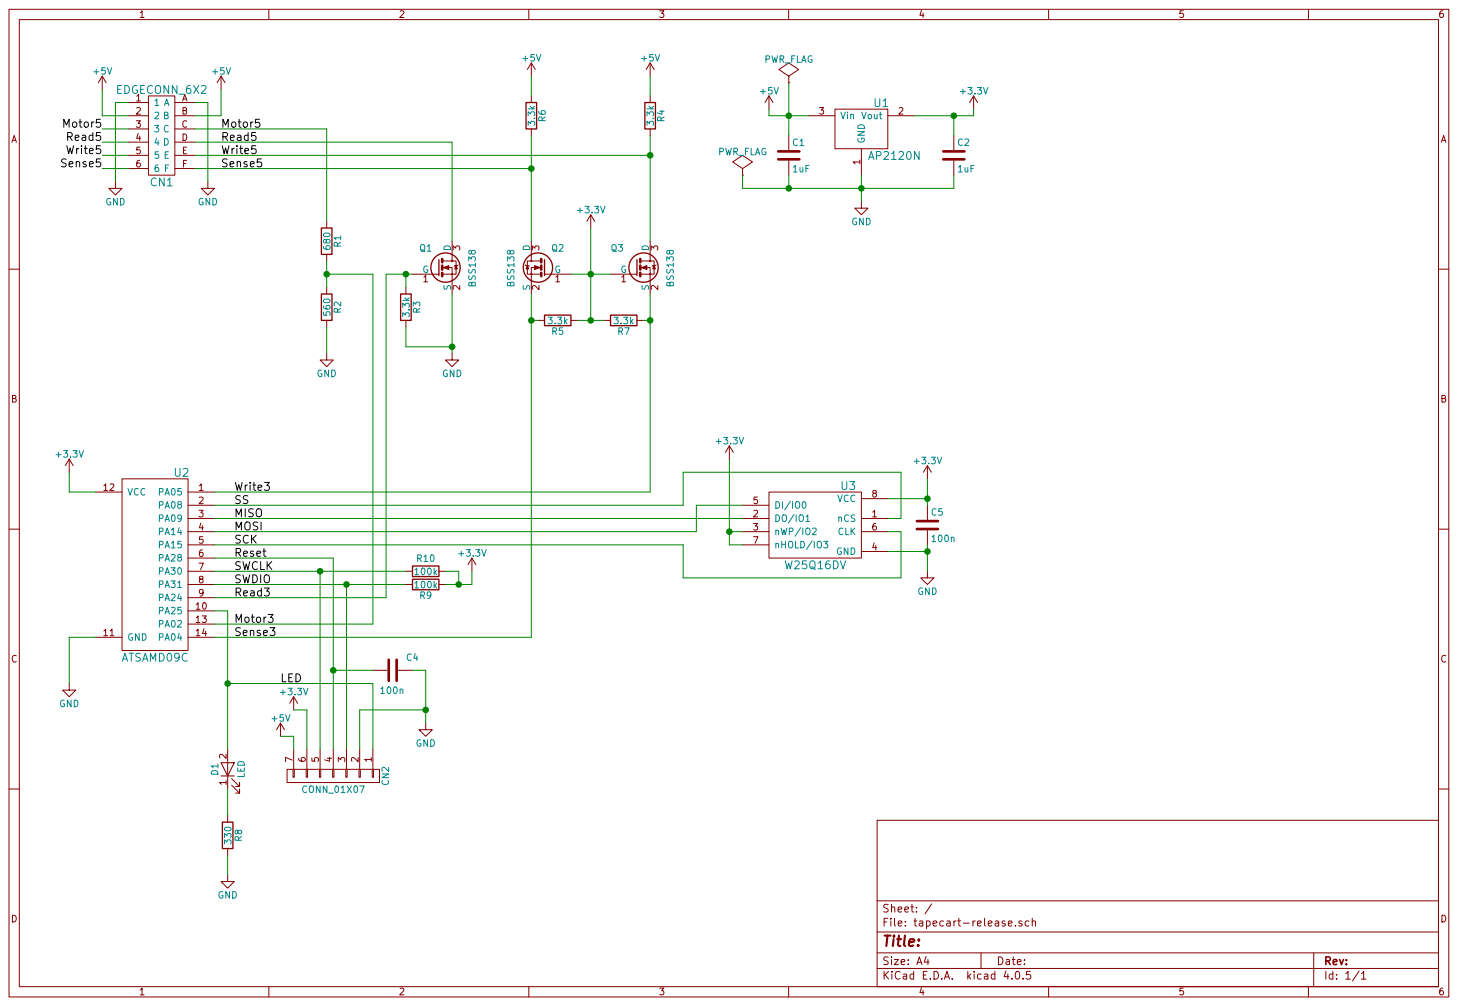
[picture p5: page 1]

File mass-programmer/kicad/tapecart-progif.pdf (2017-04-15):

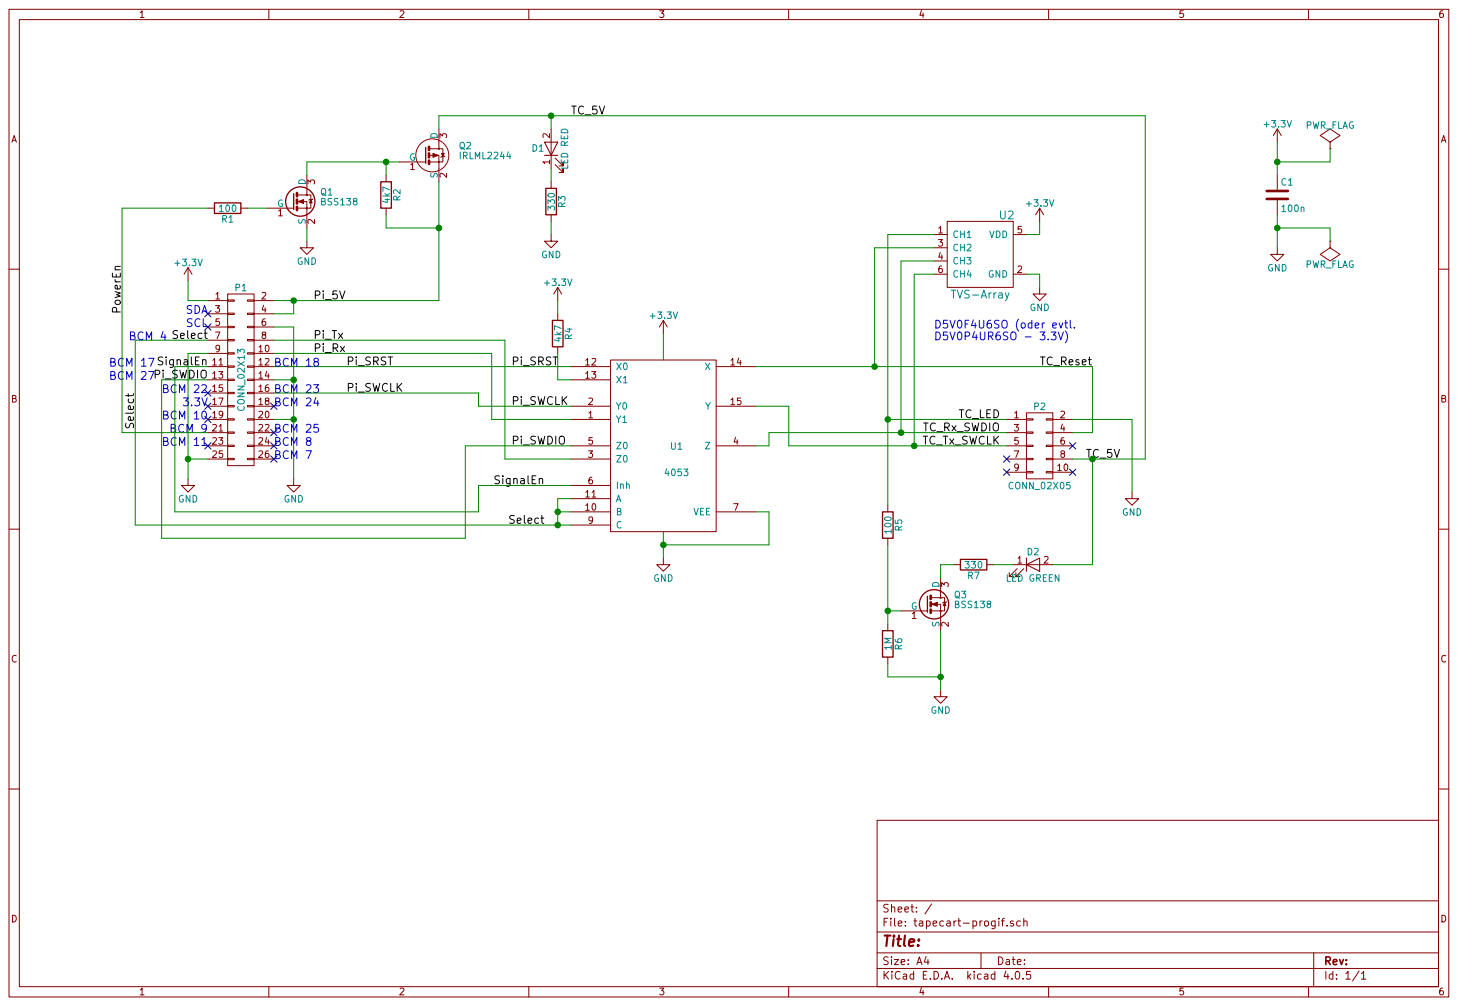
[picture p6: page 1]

9 SignalEn | 10

11 | 12 BCM 18 | Pi_SRST

File: tapecart-progif.sch Sheet: /
Id: 1/1 Title:

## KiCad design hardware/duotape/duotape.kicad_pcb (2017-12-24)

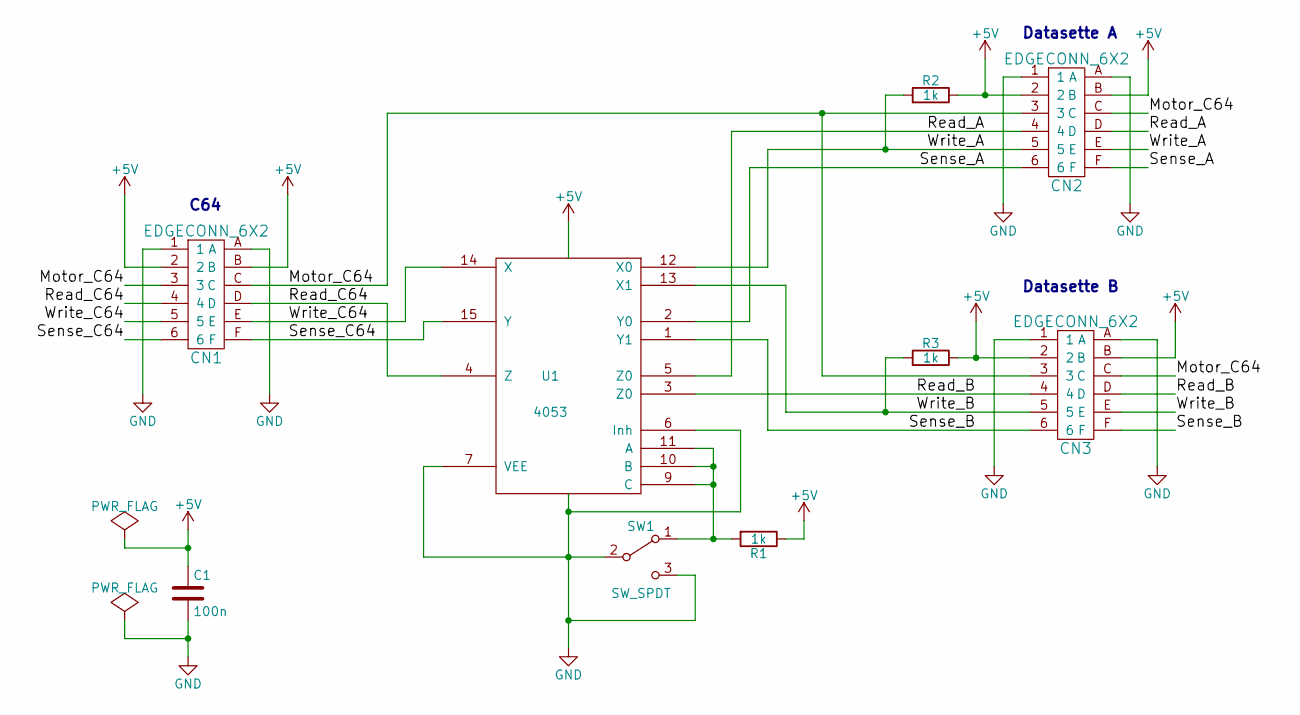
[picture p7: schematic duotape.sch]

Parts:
C1: 100n; C_Rect_L7_W2_P5
CN1, CN2: EDGECONN_6X2; EDGECONN_6x2_IMP
CN3: EDGECONN_6X2; VERTCONN_6X2
R1, R2, R3: 1k; Resistor_Horizontal_RM10mm
SW1: SW_SPDT; Switch_TL36P0
U1: 4053; DIP-16_W7.62mm

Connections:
+5V: C1.1, CN1.2, CN1.B, CN2.2, CN2.B, CN3.2, CN3.B, R1.1, R2.1, R3.1, U1.16 (VDD)
/Motor_C64: CN1.3, CN1.C, CN2.3, CN2.C, CN3.3, CN3.C
/Read_A: CN2.4, CN2.D, U1.5 (Z0)
/Read_B: CN3.4, CN3.D, U1.3 (Z0)
/Read_C64: CN1.4, CN1.D, U1.4 (Z)
/Sense_A: CN2.6, CN2.F, U1.2 (Y0)
/Sense_B: CN3.6, CN3.F, U1.1 (Y1)
/Sense_C64: CN1.6, CN1.F, U1.15 (Y)
/Write_A: CN2.5, CN2.E, R2.2, U1.12 (X0)
/Write_B: CN3.5, CN3.E, R3.2, U1.13 (X1)
/Write_C64: CN1.5, CN1.E, U1.14 (X)
GND: C1.2, CN1.1, CN1.A, CN2.1, CN2.A, CN3.1, CN3.A, SW1.2 (B), SW1.3 (C), U1.6 (Inh), U1.7 (VEE), U1.8 (VSS)
unnamed: R1.2, SW1.1 (A), U1.9 (C), U1.10 (B), U1.11 (A)

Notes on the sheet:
C64
Datasette A
Datasette B

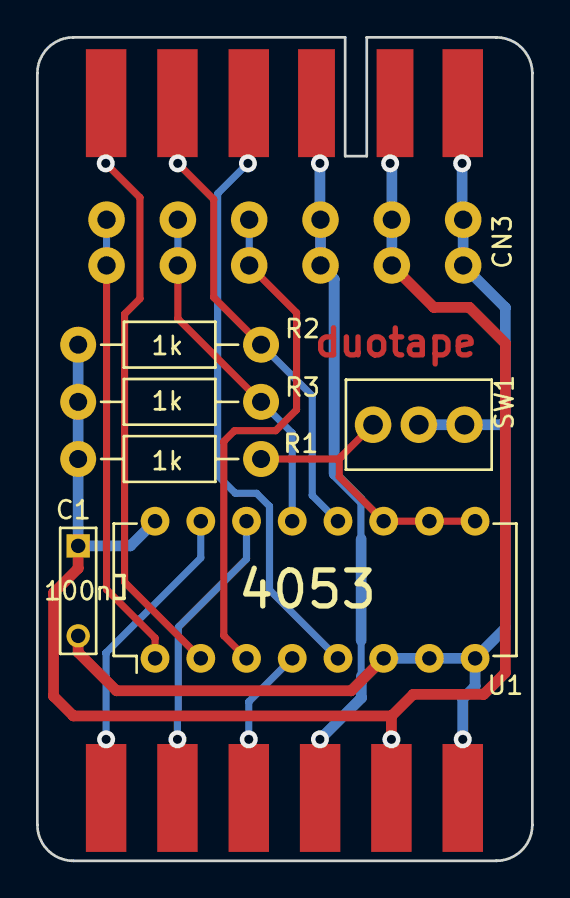
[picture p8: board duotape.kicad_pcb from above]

Board: 2 copper layers, 27.5 x 45.8 mm, 9 parts (0 on the bottom side), 13 nets.

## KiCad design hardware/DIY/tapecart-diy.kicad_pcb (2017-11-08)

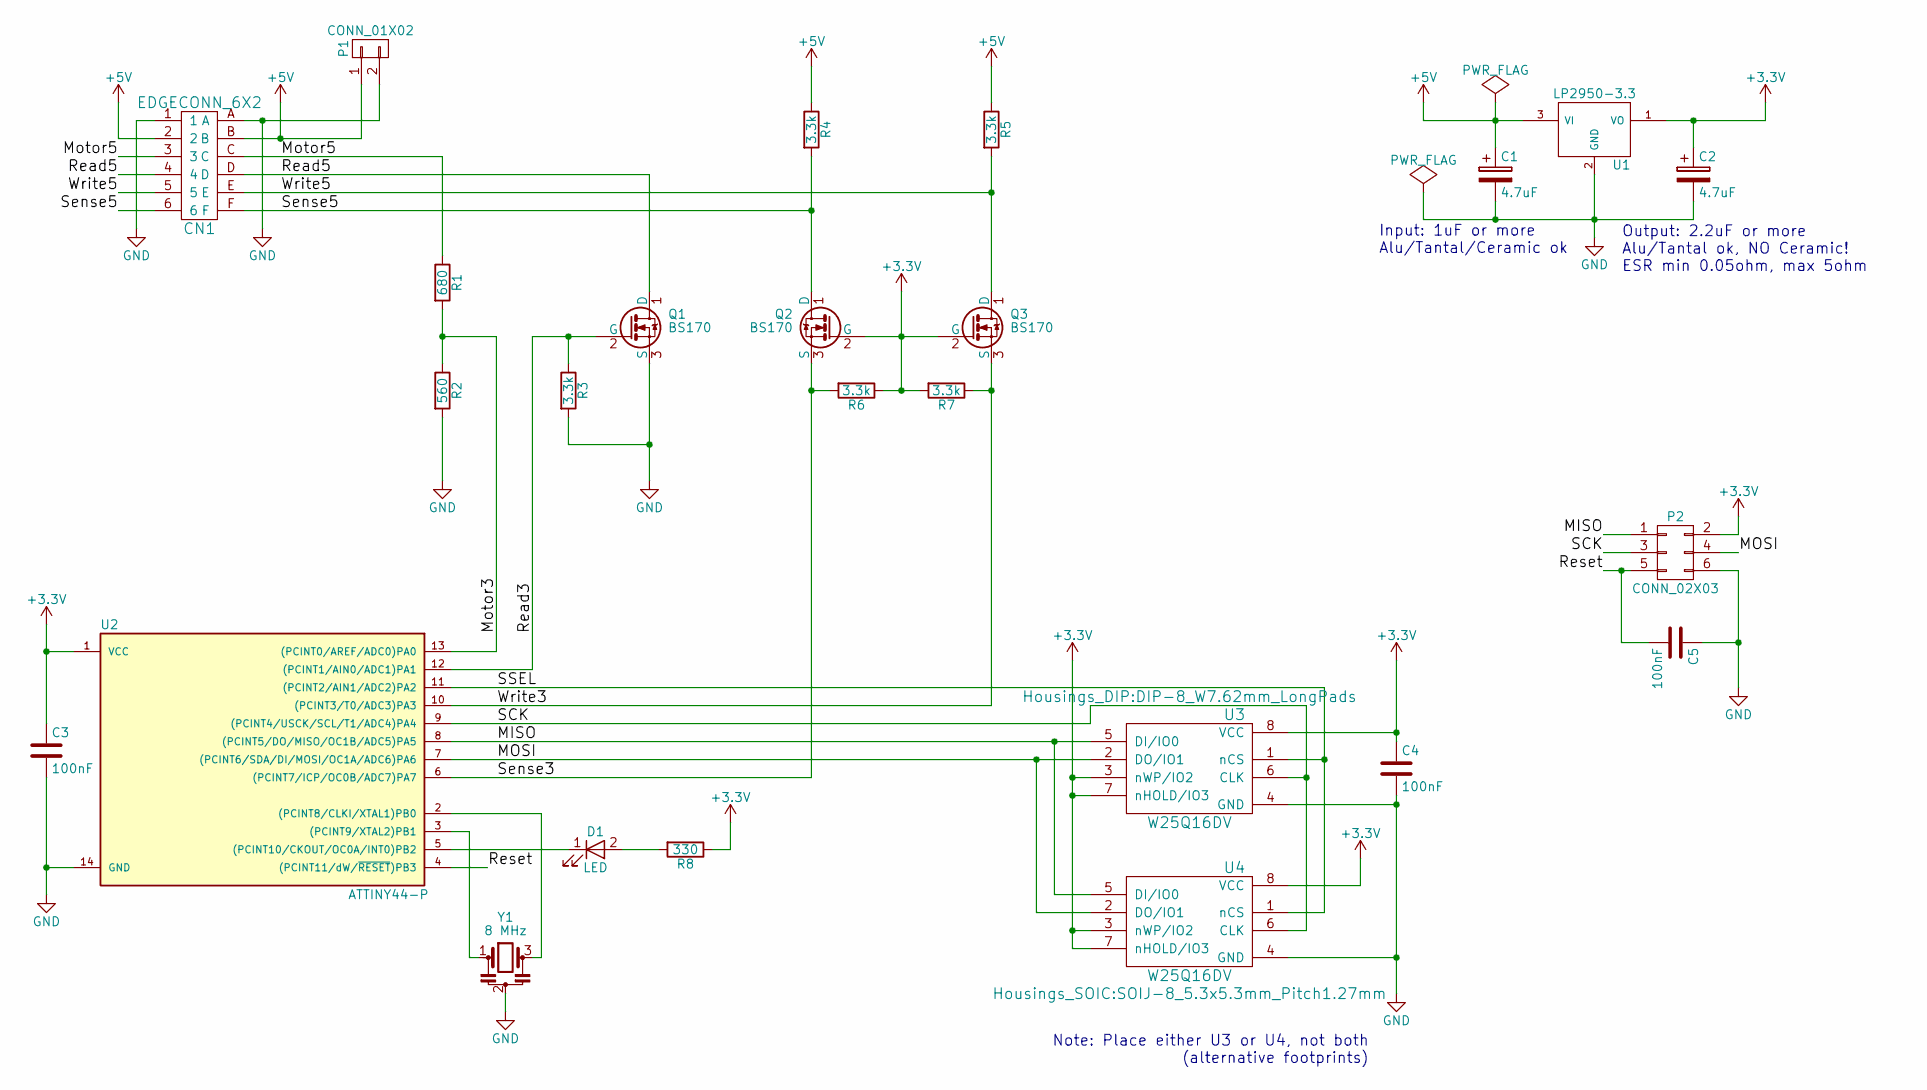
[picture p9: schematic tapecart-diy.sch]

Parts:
C1, C2: 4.7uF; C_Radial_D5_L11_P2
C3, C4, C5: 100nF; C_Disc_D3_P2.5
CN1: EDGECONN_6X2; EDGECONN_6x2_IMP_5mm
D1: LED; LED-3MM
P1: CONN_01X02; Pin_Header_Straight_1x02
P2: CONN_02X03; Pin_Header_Straight_2x03
Q1, Q2, Q3: BS170; TO-92_Inline_Wide
R1: 680; Resistor_Horizontal_RM10mm
R2: 560; Resistor_Horizontal_RM10mm
R3, R4, R5, R6, R7: 3.3k; Resistor_Horizontal_RM10mm
R8: 330; Resistor_Horizontal_RM10mm
U1: LP2950-3.3; TO-92_Inline_Wide
U2: ATTINY44-P; DIP-14_W7.62mm_LongPads
U3: W25Q16DV; DIP-8_W7.62mm_LongPads
U4: W25Q16DV; SOIJ-8_5.3x5.3mm_Pitch1.27mm
Y1: 8 MHz; Pin_Header_Straight_1x03

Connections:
+3V3: C2.1, C3.1, C4.1, P2.2, Q2.2 (G), Q3.2 (G), R6.1, R7.2, R8.1, U1.1 (VO), U2.1 (VCC), U3.3 (nWP/IO2), U3.7 (nHOLD/IO3), U3.8 (VCC), U4.3 (nWP/IO2), U4.7 (nHOLD/IO3), U4.8 (VCC)
+5V: C1.1, CN1.2, CN1.B, P1.1, R4.1, R5.1, U1.3 (VI)
/MISO: P2.1, U2.8 ((PCINT5/DO/MISO/OC1B/ADC5)PA5), U3.5 (DI/IO0), U4.5 (DI/IO0)
/MOSI: P2.4, U2.7 ((PCINT6/SDA/DI/MOSI/OC1A/ADC6)PA6), U3.2 (DO/IO1), U4.2 (DO/IO1)
/Motor3: R1.2, R2.1, U2.13 ((PCINT0/AREF/ADC0)PA0)
/Motor5: CN1.3, CN1.C, R1.1
/Read3: Q1.2 (G), R3.1, U2.12 ((PCINT1/AIN0/ADC1)PA1)
/Read5: CN1.4, CN1.D, Q1.1 (D)
/Reset: C5.2, P2.5, U2.4 ((PCINT11/dW/~RESET~)PB3)
/SCK: P2.3, U2.9 ((PCINT4/USCK/SCL/T1/ADC4)PA4), U3.6 (CLK), U4.6 (CLK)
/SSEL: U2.11 ((PCINT2/AIN1/ADC2)PA2), U3.1 (nCS), U4.1 (nCS)
/Sense3: Q2.3 (S), R6.2, U2.6 ((PCINT7/ICP/OC0B/ADC7)PA7)
/Sense5: CN1.6, CN1.F, Q2.1 (D), R4.2
/Write3: Q3.3 (S), R7.1, U2.10 ((PCINT3/T0/ADC3)PA3)
/Write5: CN1.5, CN1.E, Q3.1 (D), R5.2
GND: C1.2, C2.2, C3.2, C4.2, C5.1, CN1.1, CN1.A, P1.2, P2.6, Q1.3 (S), R2.2, R3.2, U1.2 (GND), U2.14 (GND), U3.4 (GND), U4.4 (GND), Y1.2
unnamed: D1.1 (K), U2.5 ((PCINT10/CKOUT/OC0A/INT0)PB2)
unnamed: D1.2 (A), R8.2
unnamed: U2.2 ((PCINT8/CLKI/XTAL1)PB0), Y1.3
unnamed: U2.3 ((PCINT9/XTAL2)PB1), Y1.1

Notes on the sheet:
Input: 1uF or more Alu/Tantal/Ceramic ok
Output: 2.2uF or more Alu/Tantal ok, NO Ceramic! ESR min 0.05ohm, max 5ohm
Note: Place either U3 or U4, not both (alternative footprints)

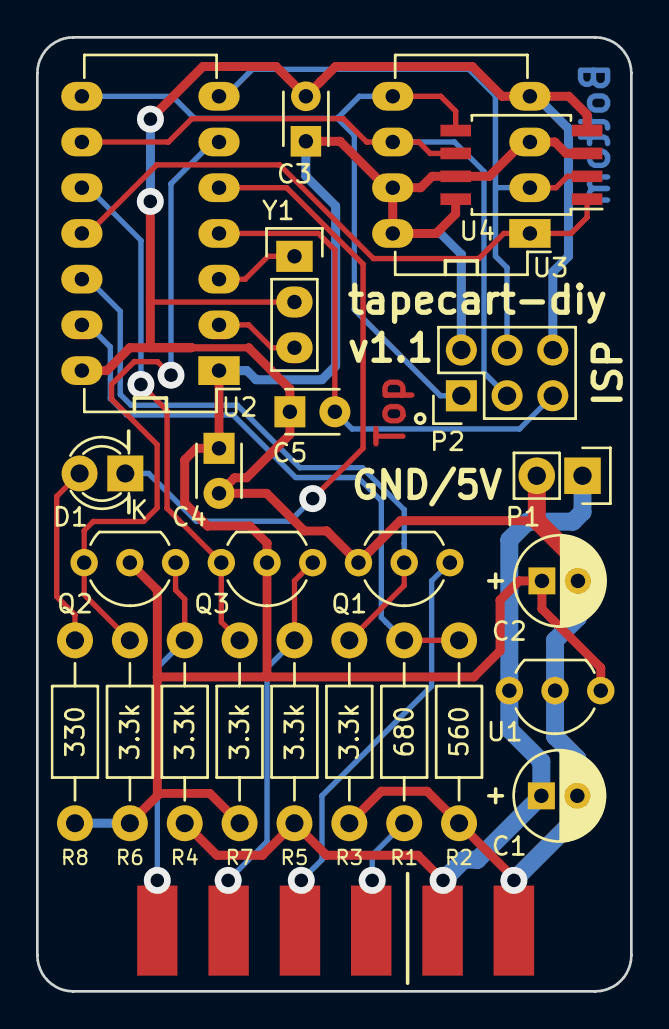
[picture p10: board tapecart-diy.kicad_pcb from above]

Board: 2 copper layers, 33.0 x 53.0 mm, 25 parts (0 on the bottom side), 20 nets.

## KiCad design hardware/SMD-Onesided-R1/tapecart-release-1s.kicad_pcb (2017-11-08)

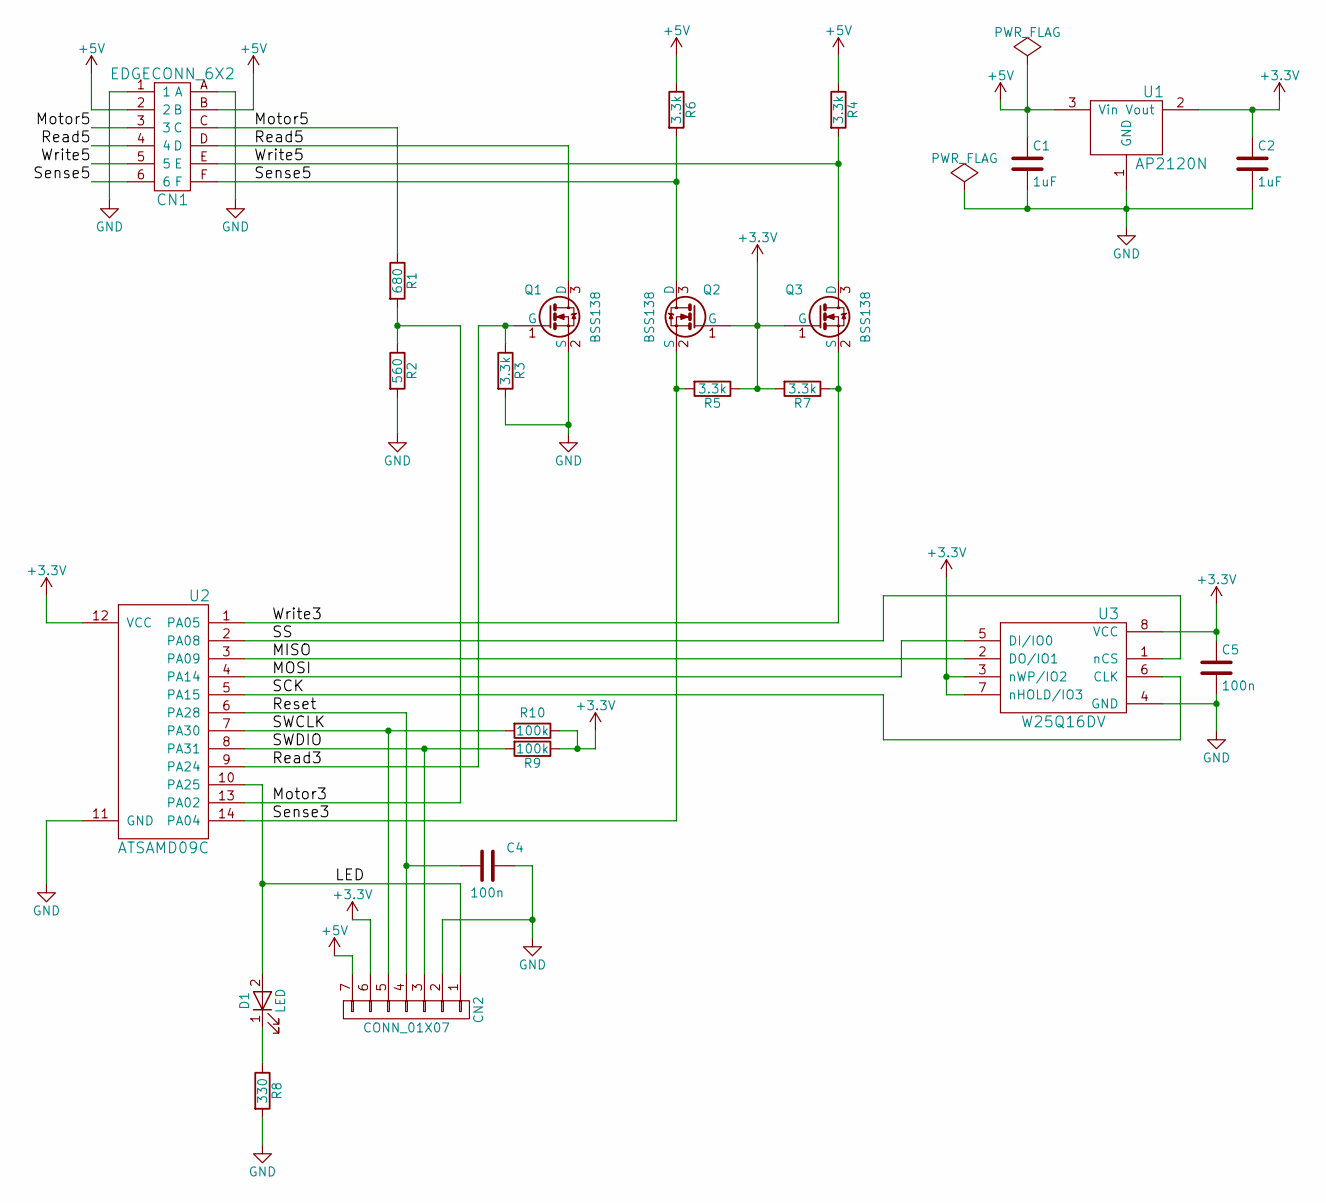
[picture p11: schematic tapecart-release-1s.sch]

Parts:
C1, C2: 1uF; C_0805
C4, C5: 100n; C_0805
CN1: EDGECONN_6X2; EDGECONN_6x2_IMP_5mm
CN2: CONN_01X07; PINHEAD_6p1X1_1.27
D1: LED; LED_0805
Q1, Q2, Q3: BSS138; SOT-23
R1: 680; R_0805
R2: 560; R_0805
R3, R4, R5, R6, R7: 3.3k; R_0805
R8: 330; R_0805
R9, R10: 100k; R_0805
U1: AP2120N; SOT-23
U2: ATSAMD09C; SOIC-14_3.9x8.7mm_Pitch1.27mm
U3: W25Q16DV; SOIC-8_3.9x4.9mm_Pitch1.27mm

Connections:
+3V3: C2.1, C5.1, CN2.6, Q2.1 (G), Q3.1 (G), R5.1, R7.2, R9.1, R10.1, U1.2 (Vout), U2.12 (VCC), U3.3 (nWP/IO2), U3.7 (nHOLD/IO3), U3.8 (VCC)
+5V: C1.1, CN1.2, CN1.B, CN2.7, R4.1, R6.1, U1.3 (Vin)
/LED: CN2.1, D1.2 (A), U2.10 (PA25)
/MISO: U2.3 (PA09), U3.2 (DO/IO1)
/MOSI: U2.4 (PA14), U3.5 (DI/IO0)
/Motor3: R1.2, R2.1, U2.13 (PA02)
/Motor5: CN1.3, CN1.C, R1.1
/Read3: Q1.1 (G), R3.1, U2.9 (PA24)
/Read5: CN1.4, CN1.D, Q1.3 (D)
/Reset: C4.2, CN2.4, U2.6 (PA28)
/SCK: U2.5 (PA15), U3.6 (CLK)
/SS: U2.2 (PA08), U3.1 (nCS)
/SWCLK: CN2.5, R10.2, U2.7 (PA30)
/SWDIO: CN2.3, R9.2, U2.8 (PA31)
/Sense3: Q2.2 (S), R5.2, U2.14 (PA04)
/Sense5: CN1.6, CN1.F, Q2.3 (D), R6.2
/Write3: Q3.2 (S), R7.1, U2.1 (PA05)
/Write5: CN1.5, CN1.E, Q3.3 (D), R4.2
GND: C1.2, C2.2, C4.1, C5.2, CN1.1, CN1.A, CN2.2, Q1.2 (S), R2.2, R3.2, R8.2, U1.1 (GND), U2.11 (GND), U3.4 (GND)
unnamed: D1.1 (K), R8.1

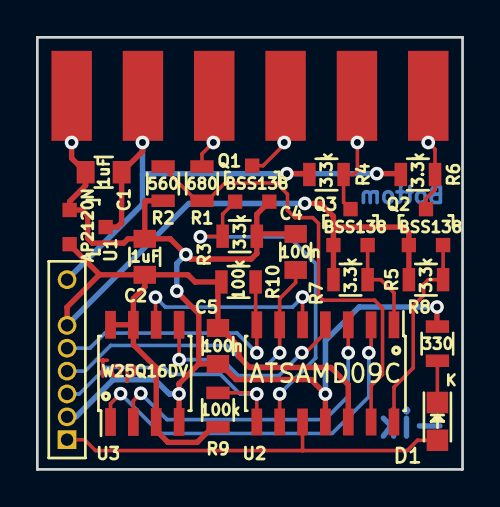
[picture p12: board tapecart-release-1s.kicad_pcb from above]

Board: 2 copper layers, 23.6 x 24.0 mm, 23 parts (0 on the bottom side), 20 nets.

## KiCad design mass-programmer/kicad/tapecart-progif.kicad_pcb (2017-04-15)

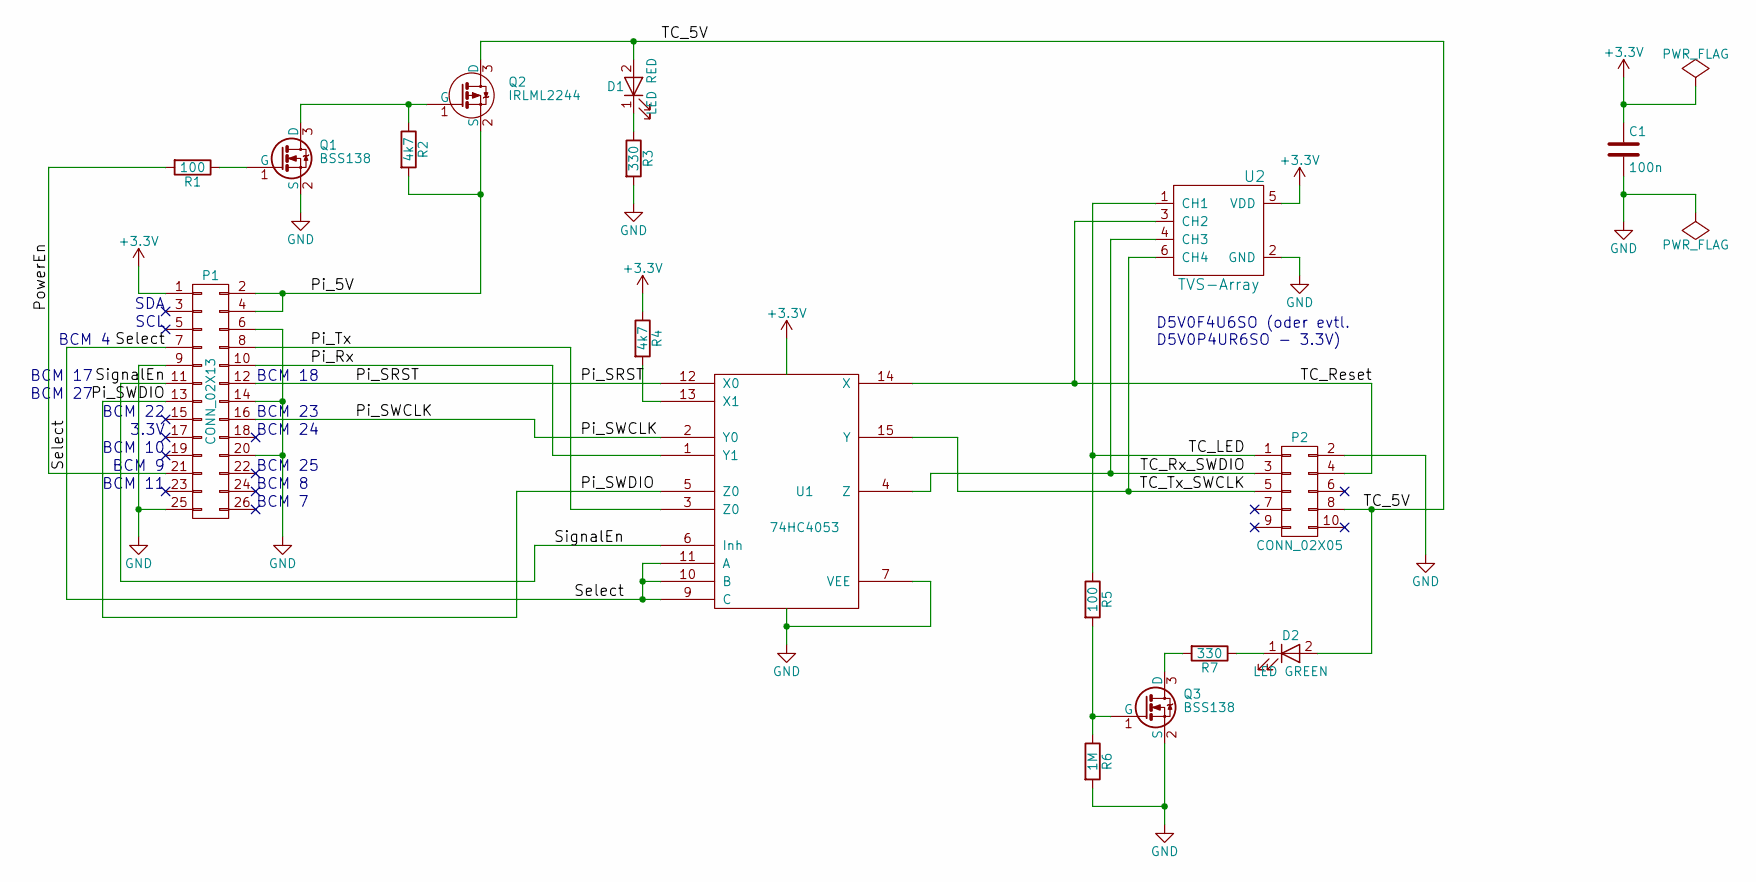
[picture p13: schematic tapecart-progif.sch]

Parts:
C1: 100n; C_0805
D1: LED RED; LED_0805
D2: LED GREEN; LED_0805
P1: CONN_02X13; Pin_Header_Straight_2x13
P2: CONN_02X05; IDC_Header_Straight_10pins
Q1, Q3: BSS138; SOT-23
Q2: IRLML2244; SOT-23
R1, R5: 100; R_0805
R2, R4: 4k7; R_0805
R3, R7: 330; R_0805
R6: 1M; R_0805
U1: 74HC4053; SOIC-16_3.9x9.9mm_Pitch1.27mm
U2: TVS-Array; SOT-23-6

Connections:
+3V3: C1.1, P1.1, R4.1, U1.16 (VDD), U2.5 (VDD)
/Pi_5V: P1.2, P1.4, Q2.2 (S), R2.2
/Pi_Rx: P1.10, U1.1 (Y1)
/Pi_SRST: P1.12, U1.12 (X0)
/Pi_SWCLK: P1.16, U1.2 (Y0)
/Pi_SWDIO: P1.13, U1.5 (Z0)
/Pi_Tx: P1.8, U1.3 (Z0)
/PowerEn: P1.21, R1.2
/Select: P1.7, U1.9 (C), U1.10 (B), U1.11 (A)
/SignalEn: P1.11, U1.6 (Inh)
/TC_5V: D1.2 (A), D2.2 (A), P2.8, Q2.3 (D)
/TC_LED: P2.1, R5.1, U2.1 (CH1)
/TC_Reset: P2.4, U1.14 (X), U2.3 (CH2)
/TC_Rx_SWDIO: P2.3, U1.4 (Z), U2.4 (CH3)
/TC_Tx_SWCLK: P2.5, U1.15 (Y), U2.6 (CH4)
GND: C1.2, P1.6, P1.9, P1.14, P1.20, P1.25, P2.2, Q1.2 (S), Q3.2 (S), R3.2, R6.2, U1.7 (VEE), U1.8 (VSS), U2.2 (GND)
unnamed: D1.1 (K), R3.1
unnamed: D2.1 (K), R7.1
unnamed: Q1.1 (G), R1.1
unnamed: Q1.3 (D), Q2.1 (G), R2.1
unnamed: Q3.1 (G), R5.2, R6.1
unnamed: Q3.3 (D), R7.2
unnamed: R4.2, U1.13 (X1)

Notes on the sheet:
D5V0F4U6SO (oder evtl. D5V0P4UR6SO - 3.3V)
SDA
SCL
BCM 27
BCM 17
BCM 22
3.3V
BCM 10
BCM 9
BCM 11
BCM 7
BCM 8
BCM 23
BCM 4
BCM 25
BCM 24
BCM 18

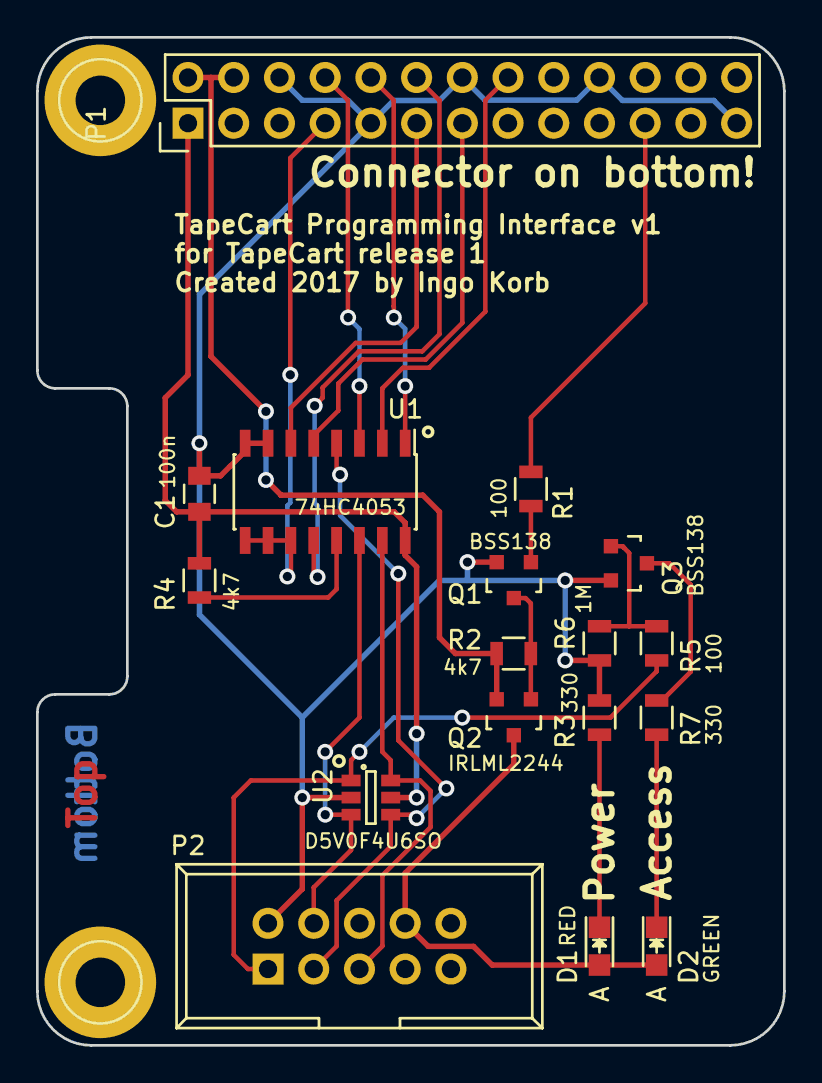
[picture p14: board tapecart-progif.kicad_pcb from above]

Board: 2 copper layers, 41.5 x 56.0 mm, 19 parts (0 on the bottom side), 23 nets.

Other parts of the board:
HOLE1, HOLE2: 1pin

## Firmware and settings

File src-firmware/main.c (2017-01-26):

/* tapecart - a tape port storage pod for the C64

   Copyright (C) 2013-2017  Ingo Korb <ingo@akana.de>
   All rights reserved.
   Idea by enthusi

   Redistribution and use in source and binary forms, with or without
   modification, are permitted provided that the following conditions
   are met:
   1. Redistributions of source code must retain the above copyright
      notice, this list of conditions and the following disclaimer.
   2. Redistributions in binary form must reproduce the above copyright
      notice, this list of conditions and the following disclaimer in the
      documentation and/or other materials provided with the distribution.

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

   main.c: Streaming and fastload modes and mode switch detection

*/

#include <stdbool.h>
#include <string.h>
#include "config.h"
#include "arch-eeprom.h"
#include "bitbanging.h"
#include "cmdmode.h"
#include "debugflags.h"
#include "extmem.h"
#include "system.h"
#include "timer.h"
#include "uart.h"
#include "utils.h"
#include "watchdog.h"

/* half-wave pulse timer values */
#define CBMPULSE_SHORT  (0x30 / 2 - 1)
#define CBMPULSE_MEDIUM (0x42 / 2 - 1)
#define CBMPULSE_LONG   (0x56 / 2 - 1)

#define SREG_MAGIC_VALUE_LOADER  0xca65
#define SREG_MAGIC_VALUE_COMMAND 0xfce2

typedef enum {
  MODE_STREAM,
  MODE_LOADER,
  MODE_C64COMMAND
} tapmode_t;

/* pulse buffer */
static volatile uint8_t tap_buffer[1 << CONFIG_TAPBUFFER_SHIFT];
static volatile uint8_t tapbuf_readidx;
static          uint8_t tapbuf_writeidx;

/* motor/write shift register and mode selection */
static volatile uint16_t  shift_reg;
static volatile tapmode_t mode = MODE_STREAM;
static volatile bool      motor_changed;

/* external flash tool detection */
static const char uart_trigger_string[] = "UARTPROG";
extern char __ramexec_start__;


/*** Interrupt handlers ***/

/* timer 0 overflow ISR for sending pulses to the C64 */
PULSETIMER_HANDLER {
  static bool first_half = false;

  if (first_half) {
    /* reset read line and let the timer overflow again */
    set_read(true);

  } else {
    uint8_t len;

    set_read(false);

    /* next pulse */
    len = tap_buffer[tapbuf_readidx];
    tapbuf_readidx = (tapbuf_readidx + 1) & (sizeof(tap_buffer) - 1);
    pulsetimer_set_pulselen(len);
  }

  first_half = !first_half;
}

/* pinchange ISR for the motor line */
MOTOR_HANDLER {
  if (get_motor()) {
    /* motor is on */
    pulsetimer_enable(true);

    /* capture write line state */
    shift_reg = (shift_reg << 1) | !!get_write();

    /* check for handshake */
    if (shift_reg == SREG_MAGIC_VALUE_LOADER) {
      mode = MODE_LOADER;
    } else if (shift_reg == SREG_MAGIC_VALUE_COMMAND) {
      mode = MODE_C64COMMAND;
    }
      
  } else {
    /* motor is off */
    pulsetimer_enable(false);
  }

  clear_motor_int();
}


/* ====================================================================== */
/* = CBM tape format generator                                          = */
/* ====================================================================== */

/* add a single pulse in the buffer, waiting for free space if req'd */
static void put_pulse(uint8_t pulse) {
  /* calculate index of next entry */
  uint8_t idx = (tapbuf_writeidx+1) & (sizeof(tap_buffer) - 1);

  /* wait until this index isn't the next-to-be-read */
  /* or the mode changes                             */
  while (idx == tapbuf_readidx) {
    if (mode != MODE_STREAM)
      break;
  }

  tap_buffer[idx] = pulse;
  tapbuf_writeidx = idx;
}

static void cbm_sync(uint16_t length) {
  for (uint16_t i = 0; i < length; i++)
    put_pulse(CBMPULSE_SHORT);
}

static void cbm_bit(uint8_t value) {
  if (value) {
    put_pulse(CBMPULSE_MEDIUM);
    put_pulse(CBMPULSE_SHORT);
  } else {
    put_pulse(CBMPULSE_SHORT);
    put_pulse(CBMPULSE_MEDIUM);
  }
}

static void cbm_byte(uint8_t value) {
  /* marker */
  put_pulse(CBMPULSE_LONG);
  put_pulse(CBMPULSE_MEDIUM);

  bool parity = true;
  for (uint8_t i = 0; i < 8; i++) {
    uint8_t bit = value & 1;

    cbm_bit(bit);
    if (bit)
      parity = !parity;

    value >>= 1;
  }

  cbm_bit(parity);
}

/* data function to transmit a header block */
static void header_datafunc(void) {
  /* transmit leader */
  uint8_t checksum = 0x03 ^ 0x02 ^ 0x03 ^ 0x04 ^ 0x03;
  cbm_byte(0x03); // load to absolute address
  cbm_byte(0x02); // start address
  cbm_byte(0x03);
  cbm_byte(0x04); // end address + 1
  cbm_byte(0x03);

  /* transmit file name */
  for (uint8_t i = 0; i < 16; i++) {
    uint8_t b = eeprom_read_byte(&mcu_eeprom.filename[i]);
    cbm_byte(b);
    checksum ^= b;
  }

  /* transmit remainder of loader */
  uint8_t *eeptr = mcu_eeprom.loadercode;

  for (uint8_t i = 0; i < 192 - 16 - 5; i++) {
    uint8_t b = eeprom_read_byte(eeptr++);
    cbm_byte(b);
    checksum ^= b;
  }

  /* reset current AVR EEPROM address to reduce chance of corruption */
  eeprom_safety();

  cbm_byte(checksum);
}

/* data function to transmit a start vector */
static void vector_datafunc(void) {
  cbm_byte(0x51);
  cbm_byte(0x03);
  cbm_byte(0x51 ^ 0x03);
}


/* transmit a data block */
static void cbm_datablock(void (*datafunc)(void)) {
  for (uint8_t repeat = 0; repeat < 2; repeat++) {
    /* send countdown sequence */
    for (uint8_t i = 9; i > 0; i--) {
      if (repeat)
        cbm_byte(i);
      else
        cbm_byte(i + 0x80);
    }

    datafunc();

    /* transmit block gap */
    put_pulse(CBMPULSE_LONG);
    cbm_sync(60); // note: should be less than the tap_buffer size
  }
}


/* ====================================================================== */
/* = simple fast loader                                                 = */
/* ====================================================================== */

static bool tx_byte(uint8_t b) {
  wdt_reset();
  if (get_motor())
    return true;

  set_led(false);
  fast_sendbyte_loader(b);
  set_led(true);

  return false;
}

/* current state: sense inactive, C64 is waiting for it to become active */
static void loader_handler(void) {
  set_led(true);
  pulsetimer_enable(false);
  motor_changed = false;

  /* enable watchdog to handle lockups */
  wdt_enable(WDTO_250MS);

  /* read data offset and len from AVR EEPROM */
  uint16_t dataofs  = eeprom_read_word(&mcu_eeprom.dataofs);
  uint16_t datalen  = eeprom_read_word(&mcu_eeprom.datalen);
  uint16_t calladdr = eeprom_read_word(&mcu_eeprom.calladdr);

  /* reset current AVR EEPROM address to reduce chance of corruption */
  eeprom_safety();

  /* read load address from external memory */
  wdt_reset();
  extmem_read_start(dataofs);
  wdt_reset();

  uint16_t loadaddr, endaddr;

  loadaddr  = extmem_read_byte(false);
  loadaddr |= (uint16_t)extmem_read_byte(false) << 8;
  datalen -= 2;
  wdt_reset();

  /* transmit header block to C64 */
  endaddr = loadaddr + datalen;
  if (tx_byte(calladdr & 0xff)) goto abort;
  if (tx_byte(calladdr >> 8))   goto abort;
  if (tx_byte(endaddr  & 0xff)) goto abort;
  if (tx_byte(endaddr  >> 8))   goto abort;
  if (tx_byte(loadaddr & 0xff)) goto abort;
  if (tx_byte(loadaddr >> 8))   goto abort;

  /* transmit data */
  while (datalen > 0) {
    datalen--;

    uint8_t b = extmem_read_byte(datalen == 0);

    if (tx_byte(b))
      break;
  }

 abort:
  set_led(false);

  /* cleanup */
  extmem_read_stop();
  wdt_disable();
}


/* ====================================================================== */
/* = init and main loop                                                 = */
/* ====================================================================== */

int main(void) {
  /* misc init calls */
  system_init();
  ioport_init();
  uart_init();
  extmem_init();
  pulsetimer_init();
  enable_interrupts();

#if defined(HAVE_UART) && defined(ALLOW_RAMEXEC)
  /* check if an external flash tool is connected */
  if (!memcmp(&__ramexec_start__, uart_trigger_string, strlen(uart_trigger_string))) {
    /* clear the marker string immediately */
    memset(&__ramexec_start__, 0xaa, 16);

    while (1) {
      uartcommand_handler();
    }
  }
#endif

  pulsetimer_enable(true);

  while (1) {
    mode      = MODE_STREAM;
    shift_reg = 0;

    /* transmit header block */
    cbm_sync(1500); // note: 500 appears to be less reliable
    cbm_datablock(header_datafunc);
    
    /* transmit the autostart vector */
    cbm_sync(1500); // note: 500 does not work
    cbm_datablock(vector_datafunc);

    /* wait until pulse buffer is empty or motor stopped */
    while (get_motor() && (tapbuf_writeidx != tapbuf_readidx)) ;

    /* fill pulse buffer with syncs */
    memset((void *)tap_buffer, CBMPULSE_SHORT, sizeof(tap_buffer));

    /* turn off sense for ~200ms to allow loading again */
    // note: restart isn't reliable if the delay is just 100ms
    set_sense(true);
    for (uint8_t i = 0; i < 200; i++) {
      delay_ms(1);
      if (mode != MODE_STREAM)
        break;
    }

    if (debug_flags & DEBUGFLAG_BLINK_MAGIC)
      blink_value(shift_reg, 16);
 
    /* check if a magic value handshake was received */
    switch (mode) {
    case MODE_LOADER:
      // delay slightly to ensure the C64 has turned the motor signal off
      delay_ms(100);
      loader_handler();
      delay_ms(200);
      break;

    case MODE_C64COMMAND:
      delay_ms(1); // ensure that the motor signal can be turned off
      c64command_handler();
      break;
      
    default:
      break;
    }

    /* set sense low and turn on pulses immediately if motor is active */
    set_sense(false);
    if (get_motor())
      pulsetimer_enable(true);
  }
}

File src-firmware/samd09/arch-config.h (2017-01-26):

/* tapecart - a tape port storage pod for the C64

   Copyright (C) 2013-2017  Ingo Korb <ingo@akana.de>
   All rights reserved.
   Idea by enthusi

   Redistribution and use in source and binary forms, with or without
   modification, are permitted provided that the following conditions
   are met:
   1. Redistributions of source code must retain the above copyright
      notice, this list of conditions and the following disclaimer.
   2. Redistributions in binary form must reproduce the above copyright
      notice, this list of conditions and the following disclaimer in the
      documentation and/or other materials provided with the distribution.

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

   arch-config.h: Architecture-specific configuration stuff

*/

#ifndef ARCH_CONFIG_H
#define ARCH_CONFIG_H

#include <stdint.h>
#include "samd09c13a.h"

#define ALLOW_RAMEXEC
#define HAVE_UART

#define READ_BIT       PORT_PA24
#define READ_PIN_NUM   24
#define SENSE_BIT      PORT_PA04
#define SENSE_PIN_NUM  4
#define WRITE_BIT      PORT_PA05
#define WRITE_PIN_NUM  5
#define MOTOR_BIT      PORT_PA02
#define MOTOR_PIN_NUM  2
#define MOTOR_EXTINT   2
#define LED_BIT        PORT_PA25
#define LED_PIN_NUM    25
#define UARTTX_BIT     PORT_PA30
#define UARTTX_PIN_NUM 30
#define UARTRX_BIT     PART_PA31
#define UARTRX_PIN_NUM 31

#define SPI_SS_PORT  PORT_PA08
#define SPI_BITCLOCK 12000000  // maximum allowed rate

#define UART_HANDLER         SERCOM1_Handler
#define UART_SERCOM          SERCOM1
#define UART_SERCOM_IRQN     SERCOM1_IRQn
#define UART_RX_PAD          1
#define UART_TX_PAD          0

static inline void ioport_init(void) {
  /* configure I/O ports */
  PORT->Group[0].CTRL.reg                   = 0xffffffffUL; // enable input synchronizers on all pins
  PORT->Group[0].DIRSET.reg                 = READ_BIT  | SENSE_BIT | LED_BIT;
  PORT->Group[0].OUTCLR.reg                 = READ_BIT  | SENSE_BIT | LED_BIT;
  PORT->Group[0].OUTSET.reg                 = WRITE_BIT;
  PORT->Group[0].PINCFG[SENSE_PIN_NUM].reg  = PORT_PINCFG_INEN | PORT_PINCFG_PULLEN;
  PORT->Group[0].PINCFG[WRITE_PIN_NUM].reg  = PORT_PINCFG_INEN | PORT_PINCFG_PULLEN;
  PORT->Group[0].PINCFG[MOTOR_PIN_NUM].reg  = PORT_PINCFG_INEN;

  /* enable both-edge interrupt for the motor line */
  EIC->CONFIG[0].reg =
    (EIC_CONFIG_SENSE0_BOTH | EIC_CONFIG_FILTEN0) << (4 * MOTOR_EXTINT);
  EIC->INTENSET.reg = (1 << MOTOR_EXTINT);
  EIC->CTRL.reg = EIC_CTRL_ENABLE;

  /* connect motor pin to EIC */
  if (MOTOR_PIN_NUM & 1) {
    PORT->Group[0].PMUX[MOTOR_PIN_NUM / 2].bit.PMUXO = PORT_PMUX_PMUXE_A; // even is unshifted
  } else {
    PORT->Group[0].PMUX[MOTOR_PIN_NUM / 2].bit.PMUXE = PORT_PMUX_PMUXE_A;
  }
  PORT->Group[0].PINCFG[MOTOR_PIN_NUM].bit.PMUXEN = 1;

  /* enable interrupt */
  NVIC_EnableIRQ(EIC_IRQn);
}

/* configure UART I/O ports (disables SWD) */
static inline void ioport_uart_init(void) {
  if (UARTRX_PIN_NUM & 1) {
    PORT->Group[0].PMUX[UARTRX_PIN_NUM / 2].bit.PMUXO = PORT_PMUX_PMUXE_C; // even is unshifted
  } else {
    PORT->Group[0].PMUX[UARTRX_PIN_NUM / 2].bit.PMUXE = PORT_PMUX_PMUXE_C;
  }      
  PORT->Group[0].PINCFG[UARTRX_PIN_NUM].reg = PORT_PINCFG_INEN | PORT_PINCFG_PMUXEN;

  if (UARTTX_PIN_NUM & 1) {
    PORT->Group[0].PMUX[UARTTX_PIN_NUM / 2].bit.PMUXO = PORT_PMUX_PMUXE_C; // even is unshifted
  } else {
    PORT->Group[0].PMUX[UARTTX_PIN_NUM / 2].bit.PMUXE = PORT_PMUX_PMUXE_C;
  }
  PORT->Group[0].PINCFG[UARTTX_PIN_NUM].bit.PMUXEN = 1;
}

typedef uint32_t uint24;

#endif

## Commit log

2017-01-14 Ensure that the device address used by flashtool is valid
2017-01-29 flashtool: UI improvements
    Add a few UI improvements to the flashtool:
    - show selected function as centered heading
    - show current device number in lower status bar
    - pre-fill fields in bootfile location function
    - show answer of "Use basic starter" question in onefiler writing
2017-01-31 flashtool: Add timeout to tapecart detection
    Add a ~5 second timeout to tapecart_cmdmode and complain about a
    missing tapecart if that timeout is reached.
    [tapecartif.c]
2017-04-15 Add mass programming interface
    [tapecart-progif-bom.csv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]
2017-08-13 flashtool: Access REU with device number 0
    Change the REU access method from a magic file name to device number 0
    to improve discoverability.
2017-11-08 Add schematics and layout files
    [tapecart-diy-1.1-prereversing.kicad_pcb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]
2017-12-24 Add duotape, a two-port tapeport switcher
    [duotape-B.Cu.gbl, duotape-B.Mask.gbs, duotape-B.SilkS.gbo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]
2017-12-26 Fix typo in READ_CAPABILITIES command name
    [cmdmode.c]
2019-06-07 remove obsolete files
    [tapecart-diy-1.1-prereversing.kicad_pcb]
2022-12-29 add eload fastloader
    [flashtool.cfg]
2022-12-29 show current menu/function in top status bar
2022-12-29 separate cart status update from status printing
